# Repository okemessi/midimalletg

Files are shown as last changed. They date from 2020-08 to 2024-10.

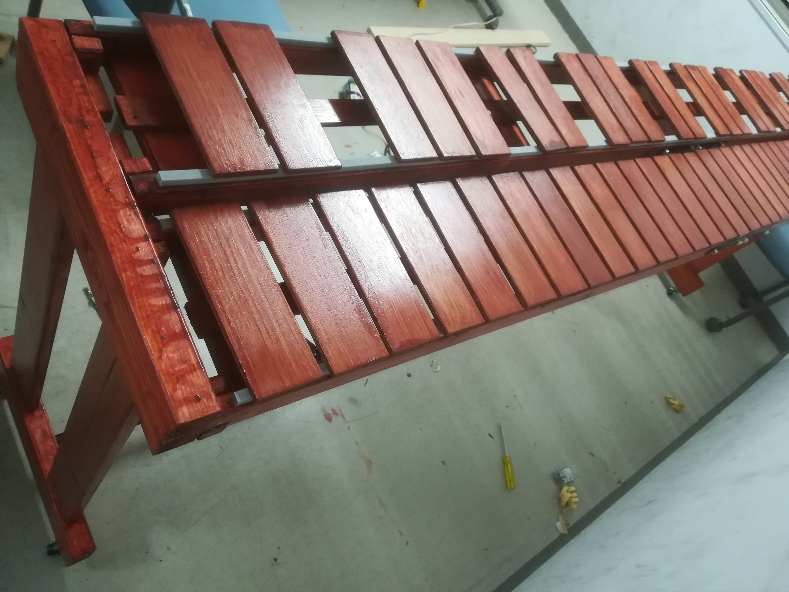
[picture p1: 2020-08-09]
docs/Hardware_example/Hardware(1).jpg

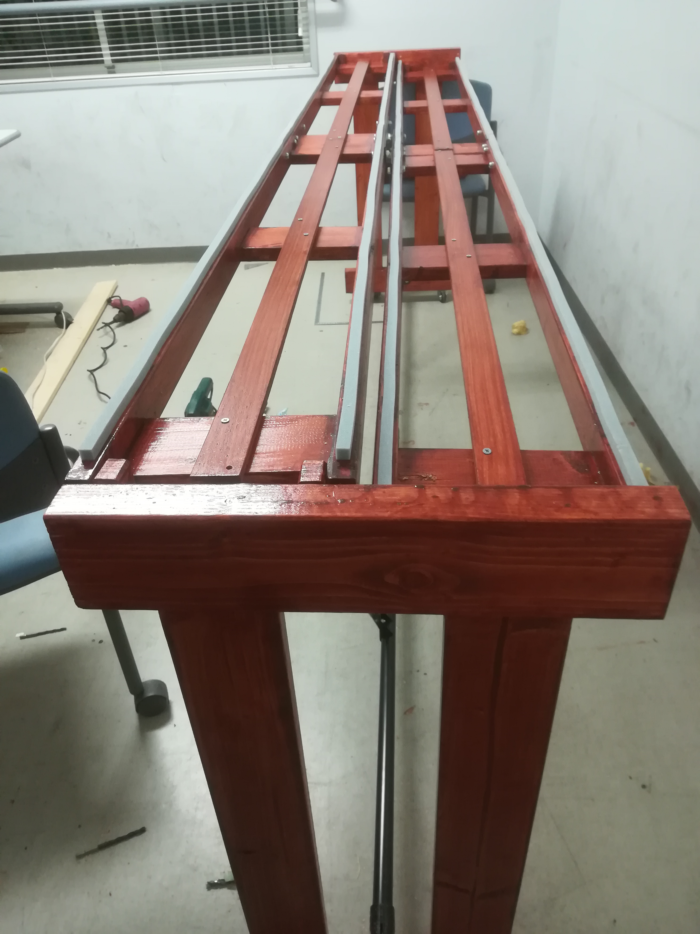
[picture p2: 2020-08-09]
docs/Hardware_example/Hardware(2).jpg

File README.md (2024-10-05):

Wiki: https://github.com/okemessi/midimalletg/wiki

# midimalletg

Midimalletg is a MIDI mallet controller for marimba/other keyboard percussion players. This project is developed as a hobby and personal project by okemessi. It is provided as-is because it is still under development. 

## Specifications

Detailed specifications will be added to the wiki page (https://github.com/okemessi/midimalletg/wiki) as they become available.

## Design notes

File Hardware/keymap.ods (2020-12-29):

id | ch |  |  | Key | +ofs | id | ch |  |  | Key | +ofs | id | ch
0 | 0 |  |  |  |  | 4 | 0 | SW | 1 | 0 | 16 | 8 | 0 | calib
 | 1 | NW | 1 | 1 | 17 |  | 1 |  | 2 | 2 | 18 |  | 1 | fader0
 | 2 |  | 2 | 3 | 19 |  | 2 |  | 3 | 4 | 20 |  | 2 | fader1
 | 3 |  | 3 | 6 | 22 |  | 3 |  | 4 | 5 | 21 |  | 3 | fader2
 | 4 |  | 4 | 8 | 24 |  | 4 |  | 5 | 7 | 23 |  | 4 | exp1
 | 5 |  | 5 | 10 | 26 |  | 5 |  | 6 | 9 | 25 |  | 5 | exp2
 | 6 |  | 6 | 13 | 29 |  | 6 |  | 7 | 11 | 27 |  | 6
 | 7 |  | 7 | 15 | 31 |  | 7 |  | 8 | 12 | 28 |  | 7
1 | 0 | NW | 8 | 18 | 34 | 5 | 0 | SW | 9 | 14 | 30 | 9 | 0 | button0
 | 1 |  | 9 | 20 | 36 |  | 1 |  | 10 | 16 | 32 |  | 1 | button1
 | 2 |  | 10 | 22 | 38 |  | 2 |  | 11 | 17 | 33 |  | 2 | button2
 | 3 |  | 11 | 25 | 41 |  | 3 |  | 12 | 19 | 35 |  | 3 | button3
 | 4 | SE | 1 | 28 | 44 | 5 | 4 |  | 13 | 21 | 37 |  | 4 | oct+
 | 5 |  | 2 | 29 | 45 |  | 5 |  | 14 | 23 | 39 |  | 5 | oct-
 | 6 |  | 3 | 31 | 47 |  | 6 |  | 15 | 24 | 40 |  | 6 | pedal1
 | 7 |  | 4 | 33 | 49 |  | 7 |  | 16 | 26 | 42 |  | 7 | pedal2
2 | 0 | SE | 5 | 35 | 51 | 6 | 0 | NE | 1 | 27 | 43
 | 1 |  | 6 | 36 | 52 |  | 1 |  | 2 | 30 | 46
 | 2 |  | 7 | 38 | 54 |  | 2 |  | 3 | 32 | 48
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

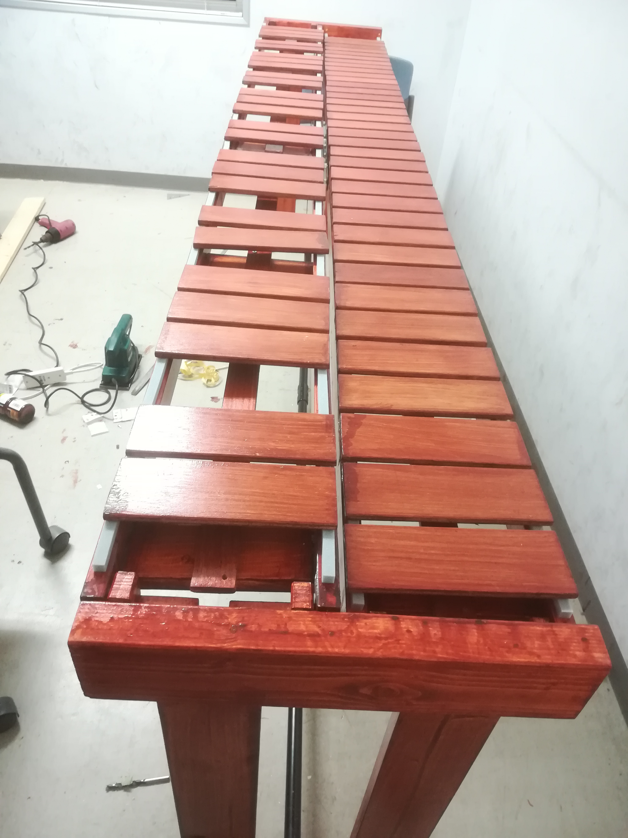
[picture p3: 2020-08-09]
docs/Hardware_example/Hardware.jpg

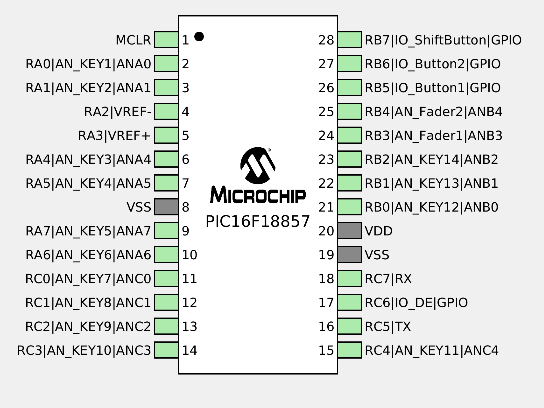
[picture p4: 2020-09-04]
docs/MCUs_pin_assign/chip4.png

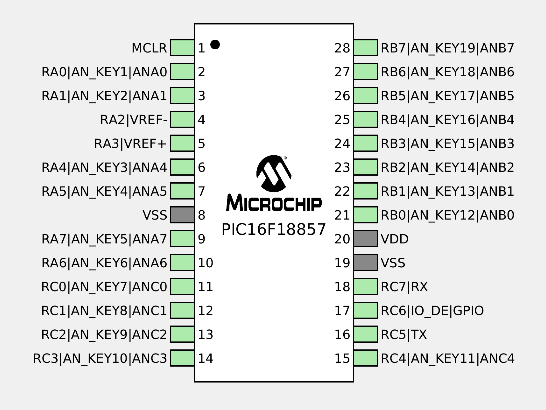
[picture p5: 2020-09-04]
docs/MCUs_pin_assign/chip3.png

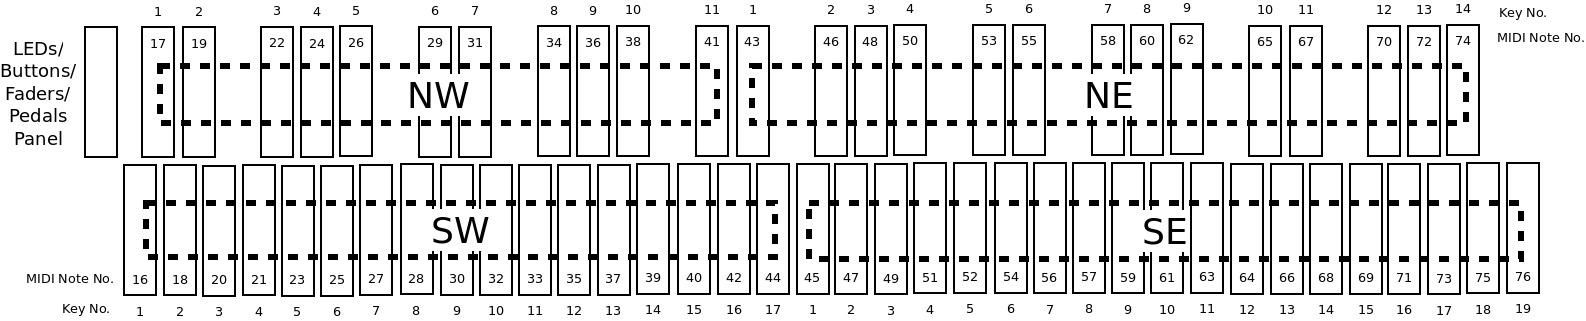
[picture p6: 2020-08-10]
docs/keymap/keymap.png

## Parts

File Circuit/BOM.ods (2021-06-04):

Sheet: Packed
Reference | Value | Reference | Value | quantity |  | Footprint | Datasheet | fader
R21 | 220 | R-25221 | 100 | 1 | 100 | 100 | ~ | Mother
U1 | 4051 | I-10914 | 40 | 11 | 440 | Package_DIP:DIP-16_W7.62mm | http://www.intersil.com/content/dam/Intersil/documents/cd40/cd4051bms-52bms-53bms.pdf | fader
C3 | 0.01u | P-11150 | 5 | 1 | 5 | Capacitor_THT:C_Disc_D3.0mm_W2.0mm_P2.50mm | ~ | Display
C2 | 0.1u | P-00090 | 100 | 4 | 400 | Capacitor_THT:C_Disc_D3.0mm_W1.6mm_P2.50mm | ~ | fader
R1 | 10k | R-25103 | 100 | 1 | 100 | Resistor_THT:R_Axial_DIN0204_L3.6mm_D1.6mm_P7.62mm_Horizontal | ~ | fader
C1 | 10u | P-06197 | 80 | 2 | 160 | Capacitor_THT:CP_Radial_D5.0mm_P2.50mm | ~ | fader
C22 | 10uF | P-05103 | 30 | 1 | 30 | Capacitor_THT:C_Disc_D5.0mm_W2.5mm_P5.00mm | ~ | Mother
R3 | 1k | R-25102 | 100 | 1 | 100 | Resistor_THT:R_Axial_DIN0204_L3.6mm_D1.6mm_P7.62mm_Horizontal | ~ | Mother
R1 | 1Meg | R-07866 | 100 | 1 | 100 | Resistor_THT:R_Axial_DIN0204_L3.6mm_D1.6mm_P7.62mm_Horizontal | ~ | terminal5
D3 | I-08332 | I-08332 | 10 | 1 | 10 | Diode_THT:D_DO-41_SOD81_P2.54mm_Vertical_AnodeUp | http://www.vishay.com/docs/88503/1n4001.pdf | Mother
D2 | 1SS178 | I-10516 | 10 | 1 | 10 | Diode_THT:D_DO-35_SOD27_P2.54mm_Vertical_AnodeUp | ~ | Mother
R10 | 4.7k | R-25472 | 100 | 1 | 100 | Resistor_THT:R_Axial_DIN0204_L3.6mm_D1.6mm_P7.62mm_Horizontal | ~ | Display
RV5 | 50kA | P-07210 | 40 | 1 | 40 |  | ~ | peripheral
RV4 | 50KB | P-09239 | 100 | 4 | 400 |  | ~ | peripheral
U1 | 74HC00 | I-14052 | 20 | 2 | 40 | Package_DIP:DIP-14_W7.62mm | http://www.ti.com/lit/gpn/sn74hc00 | Mother
J12 | AudioJack2 | C-14813 | 70 | 2 | 140 |  | ~ | peripheral
J10 | AudioJack3_SwitchTR | C-06765 | 90 | 2 | 180 |  | ~ | peripheral
U2 | BP5293-33 | M-15148 | 250 | 1 | 250 | Package_TO_SOT_THT:TO-220-3_Vertical | https://akizukidenshi.com/download/ds/rohm/BP5293_DataSheet_J_VerC_161013.pdf | Mother
U3 | BP5293-50 | M-15209 | 250 | 1 | 250 | Package_TO_SOT_THT:TO-220-3_Vertical | https://akizukidenshi.com/download/ds/rohm/BP5293_DataSheet_J_VerC_161013.pdf | Mother
J7 | Conn_01x02_Female | C-05779 | 80 | 3 | 240 |  | ~ | peripheral
J3 | Conn_01x02_Male | C-01627 | 50 | 3 | 150 | Connector_PinHeader_2.54mm:PinHeader_1x02_P2.54mm_Horizontal | ~ | fader
J9 | Conn_02x08_Female | C-05780 | 100 | 3 | 300 |  | ~ | peripheral
J2 | Conn_02x08_Male | C-00148 | 100 | 3 | 300 | Connector_PinHeader_2.54mm:PinHeader_2x08_P2.54mm_Horizontal | ~ | terminal5
J44 | DB15_Female | C-00026 | 50 | 1 | 50 |  | ~ | peripheral
J41 | DB15_Male | C-00025 | 50 | 1 | 50 |  | ~ | peripheral
 | DB15_Shell | C-00032 | 100 | 2 | 200
J26 | DIN-5_180degree | C-10456 | 60 | 2 | 120 |  | http://www.mouser.com/ds/2/18/40_c091_abd_e-75918.pdf | peripheral
BAR1 | HDSP-4830_2 | I-05347 | 120 | 1 | 120 | Display:HDSP-4830 | https://docs.broadcom.com/docs/AV02-1798EN | Display
J28 | Jack-DC | C-06299 | 40 | 1 | 40 |  | ~ | peripheral
D1 | LED | I-11655 | 20 | 1 | 20 | LED_THT:LED_D3.0mm,2.1v | ~ | Mother
D4 | LED | I-11657 | 20 | 4 | 80 | LED_THT:LED_D3.0mm | ~ | Display
AFF4 | LTS-6960HR | I-00639 | 40 | 3 | 120 | Display_7Segment:7SegmentLED_LTS6760_LTS6780 | https://datasheet.octopart.com/LTS-6960HR-Lite-On-datasheet-11803242.pdf | Display
AFF5 | LTS-6960HR | I-12923 | 50 | 2 | 100 | Display_7Segment:7SegmentLED_LTS6760_LTS6780 | https://datasheet.octopart.com/LTS-6960HR-Lite-On-datasheet-11803242.pdf | Display
U2 | PIC16F18854-SO | I-11888 | 170 | 1 | 170 | Package_DIP:DIP-28_W7.62mm | http://ww1.microchip.com/downloads/en/DeviceDoc/PIC16(L)F18854%20Data%20Sheet_DS40001826C.pdf | Display
U4 | PIC32MX110F016B-I_SP | I-05849 | 180 | 1 | 180 | Package_DIP:DIP-28_W7.62mm | http://ww1.microchip.com/downloads/en/DeviceDoc/61168E.pdf | Manufacturer URL | http://www.microchip.com | Package Specification | http://www.microchip.com/stellent/groups/techpub_sg/documents/packagingspec/en012702.pdf | Product URL | http://www.microchip.com/PIC32MX110F016B | Rev. E | Through Hole | 28-Lead Plastic Dual In-Line, 34.86 x 6.79 mm Body, 2.54 mm Pitch | C04-070B | IC | 1156563 | yes | fa7413a09ebb98f6 | Microchip | SPDIP-SP28 | 1359970709 | E7E3DC04-7D64-40B1-9461-E4D614E67543 | Mother
MK1 | Piezo | P-09799 | 70 | 61 | 4270 |  | ~ | peripheral
F1 | RXEF050 | P-01355 | 30 | 1 | 30 | Capacitor_THT:C_Disc_D8.0mm_W2.5mm_P5.00mm | https://akizukidenshi.com/download/ds/tyco/rxef050.pdf | Mother
SW1 | SW_Panel | P-15666 | 65 | 4 | 260 |  | ~ | peripheral
SW2 | SW_Panel | P-15665 | 65 | 2 | 130 |  | ~ | peripheral
SW3 | SW_Panel | P-15667 | 65 | 2 | 130 |  | ~ | peripheral
U1 | TBD62783A | I-10957 | 60 | 1 | 60 | Package_DIP:DIP-18_W7.62mm | http://toshiba.semicon-storage.com/info/docget.jsp?did=30523&prodName=TBD62783APG | Display
U6 | TLP785 | I-07554 | 20 | 1 | 20 | Package_DIP:DIP-4_W7.62mm | https://toshiba.semicon-storage.com/info/docget.jsp?did=10569&prodName=TLP785 | Mother
U3 | ULN2803A | I-15065 | 50 | 1 | 50 | Package_DIP:DIP-18_W7.62mm | http://www.ti.com/lit/ds/symlink/uln2803a.pdf | Display
Board | Ctype | P-00517 | 60 | 10 | 600
 | Atype | P-07618 | 300 | 2 | 600
knob | fader | P-09246 | 30 | 4 | 120
 | vol | P-00253 | 20 | 1 | 20
snap | MPLAB | M-13854 | 2800 | 1 | 2800
 | vinyl wire | P-11091 | 600 | 2 | 1200
 | vinyl wire | P-11090 | 600 | 2 | 1200
 | Tin-plated wire | P-02220 | 230 | 1 | 230
sw | toggle | P-03774 | 80 | 1 | 80
 |  | P-14523 | 320 | 1 | 320
 | AudioJack2 | C-14813 | 70 | 2 | 140
 |  | P-15128 | 115 | 1 | 115

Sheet: BOM
Reference | Value | Footprint | Datasheet | fader
R21 | 220 | Resistor_THT:R_Axial_DIN0204_L3.6mm_D1.6mm_P7.62mm_Horizontal | ~ | Mother
R20 | 220 | Resistor_THT:R_Axial_DIN0204_L3.6mm_D1.6mm_P7.62mm_Horizontal | ~ | Mother
R22 | 220 | Resistor_THT:R_Axial_DIN0204_L3.6mm_D1.6mm_P7.62mm_Horizontal | ~ | Mother
R23 | 220 | Resistor_THT:R_Axial_DIN0204_L3.6mm_D1.6mm_P7.62mm_Horizontal | ~ | Mother
R1 | 220 | Resistor_THT:R_Axial_DIN0204_L3.6mm_D1.6mm_P7.62mm_Horizontal | ~ | Display
R7 | 220 | Resistor_THT:R_Axial_DIN0204_L3.6mm_D1.6mm_P7.62mm_Horizontal | ~ | Display
R6 | 220 | Resistor_THT:R_Axial_DIN0204_L3.6mm_D1.6mm_P7.62mm_Horizontal | ~ | Display
R5 | 220 | Resistor_THT:R_Axial_DIN0204_L3.6mm_D1.6mm_P7.62mm_Horizontal | ~ | Display
R4 | 220 | Resistor_THT:R_Axial_DIN0204_L3.6mm_D1.6mm_P7.62mm_Horizontal | ~ | Display
R3 | 220 | Resistor_THT:R_Axial_DIN0204_L3.6mm_D1.6mm_P7.62mm_Horizontal | ~ | Display
R2 | 220 | Resistor_THT:R_Axial_DIN0204_L3.6mm_D1.6mm_P7.62mm_Horizontal | ~ | Display
R9 | 220 | Resistor_THT:R_Axial_DIN0204_L3.6mm_D1.6mm_P7.62mm_Horizontal | ~ | terminal5
R10 | 220 | Resistor_THT:R_Axial_DIN0204_L3.6mm_D1.6mm_P7.62mm_Horizontal | ~ | terminal5
R11 | 220 | Resistor_THT:R_Axial_DIN0204_L3.6mm_D1.6mm_P7.62mm_Horizontal | ~ | terminal5
R12 | 220 | Resistor_THT:R_Axial_DIN0204_L3.6mm_D1.6mm_P7.62mm_Horizontal | ~ | terminal5
R13 | 220 | Resistor_THT:R_Axial_DIN0204_L3.6mm_D1.6mm_P7.62mm_Horizontal | ~ | terminal5
R14 | 220 | Resistor_THT:R_Axial_DIN0204_L3.6mm_D1.6mm_P7.62mm_Horizontal | ~ | terminal5
R15 | 220 | Resistor_THT:R_Axial_DIN0204_L3.6mm_D1.6mm_P7.62mm_Horizontal | ~ | terminal5
R16 | 220 | Resistor_THT:R_Axial_DIN0204_L3.6mm_D1.6mm_P7.62mm_Horizontal | ~ | terminal5
R9 | 220 | Resistor_THT:R_Axial_DIN0204_L3.6mm_D1.6mm_P7.62mm_Horizontal | ~ | terminal7
R10 | 220 | Resistor_THT:R_Axial_DIN0204_L3.6mm_D1.6mm_P7.62mm_Horizontal | ~ | terminal7
R11 | 220 | Resistor_THT:R_Axial_DIN0204_L3.6mm_D1.6mm_P7.62mm_Horizontal | ~ | terminal7
R12 | 220 | Resistor_THT:R_Axial_DIN0204_L3.6mm_D1.6mm_P7.62mm_Horizontal | ~ | terminal7
R13 | 220 | Resistor_THT:R_Axial_DIN0204_L3.6mm_D1.6mm_P7.62mm_Horizontal | ~ | terminal7
R14 | 220 | Resistor_THT:R_Axial_DIN0204_L3.6mm_D1.6mm_P7.62mm_Horizontal | ~ | terminal7
R15 | 220 | Resistor_THT:R_Axial_DIN0204_L3.6mm_D1.6mm_P7.62mm_Horizontal | ~ | terminal7
R16 | 220 | Resistor_THT:R_Axial_DIN0204_L3.6mm_D1.6mm_P7.62mm_Horizontal | ~ | terminal7
R9 | 220 | Resistor_THT:R_Axial_DIN0204_L3.6mm_D1.6mm_P7.62mm_Horizontal | ~ | terminal4N
R10 | 220 | Resistor_THT:R_Axial_DIN0204_L3.6mm_D1.6mm_P7.62mm_Horizontal | ~ | terminal4N
R11 | 220 | Resistor_THT:R_Axial_DIN0204_L3.6mm_D1.6mm_P7.62mm_Horizontal | ~ | terminal4N
R12 | 220 | Resistor_THT:R_Axial_DIN0204_L3.6mm_D1.6mm_P7.62mm_Horizontal | ~ | terminal4N
R13 | 220 | Resistor_THT:R_Axial_DIN0204_L3.6mm_D1.6mm_P7.62mm_Horizontal | ~ | terminal4N
R14 | 220 | Resistor_THT:R_Axial_DIN0204_L3.6mm_D1.6mm_P7.62mm_Horizontal | ~ | terminal4N
R15 | 220 | Resistor_THT:R_Axial_DIN0204_L3.6mm_D1.6mm_P7.62mm_Horizontal | ~ | terminal4N
R16 | 220 | Resistor_THT:R_Axial_DIN0204_L3.6mm_D1.6mm_P7.62mm_Horizontal | ~ | terminal4N
R9 | 220 | Resistor_THT:R_Axial_DIN0204_L3.6mm_D1.6mm_P7.62mm_Horizontal | ~ | terminal4S
R10 | 220 | Resistor_THT:R_Axial_DIN0204_L3.6mm_D1.6mm_P7.62mm_Horizontal | ~ | terminal4S
R11 | 220 | Resistor_THT:R_Axial_DIN0204_L3.6mm_D1.6mm_P7.62mm_Horizontal | ~ | terminal4S
R12 | 220 | Resistor_THT:R_Axial_DIN0204_L3.6mm_D1.6mm_P7.62mm_Horizontal | ~ | terminal4S
R13 | 220 | Resistor_THT:R_Axial_DIN0204_L3.6mm_D1.6mm_P7.62mm_Horizontal | ~ | terminal4S
R14 | 220 | Resistor_THT:R_Axial_DIN0204_L3.6mm_D1.6mm_P7.62mm_Horizontal | ~ | terminal4S
R15 | 220 | Resistor_THT:R_Axial_DIN0204_L3.6mm_D1.6mm_P7.62mm_Horizontal | ~ | terminal4S
R16 | 220 | Resistor_THT:R_Axial_DIN0204_L3.6mm_D1.6mm_P7.62mm_Horizontal | ~ | terminal4S
R9 | 220 | Resistor_THT:R_Axial_DIN0204_L3.6mm_D1.6mm_P7.62mm_Horizontal | ~ | terminal1-2-3-6
R10 | 220 | Resistor_THT:R_Axial_DIN0204_L3.6mm_D1.6mm_P7.62mm_Horizontal | ~ | terminal1-2-3-6
R11 | 220 | Resistor_THT:R_Axial_DIN0204_L3.6mm_D1.6mm_P7.62mm_Horizontal | ~ | terminal1-2-3-6
R12 | 220 | Resistor_THT:R_Axial_DIN0204_L3.6mm_D1.6mm_P7.62mm_Horizontal | ~ | terminal1-2-3-6
R13 | 220 | Resistor_THT:R_Axial_DIN0204_L3.6mm_D1.6mm_P7.62mm_Horizontal | ~ | terminal1-2-3-6
R14 | 220 | Resistor_THT:R_Axial_DIN0204_L3.6mm_D1.6mm_P7.62mm_Horizontal | ~ | terminal1-2-3-6
R15 | 220 | Resistor_THT:R_Axial_DIN0204_L3.6mm_D1.6mm_P7.62mm_Horizontal | ~ | terminal1-2-3-6
R16 | 220 | Resistor_THT:R_Axial_DIN0204_L3.6mm_D1.6mm_P7.62mm_Horizontal | ~ | terminal1-2-3-6
R9 | 220 | Resistor_THT:R_Axial_DIN0204_L3.6mm_D1.6mm_P7.62mm_Horizontal | ~ | terminal1-2-3-6
R10 | 220 | Resistor_THT:R_Axial_DIN0204_L3.6mm_D1.6mm_P7.62mm_Horizontal | ~ | terminal1-2-3-6
R11 | 220 | Resistor_THT:R_Axial_DIN0204_L3.6mm_D1.6mm_P7.62mm_Horizontal | ~ | terminal1-2-3-6
R12 | 220 | Resistor_THT:R_Axial_DIN0204_L3.6mm_D1.6mm_P7.62mm_Horizontal | ~ | terminal1-2-3-6
R13 | 220 | Resistor_THT:R_Axial_DIN0204_L3.6mm_D1.6mm_P7.62mm_Horizontal | ~ | terminal1-2-3-6
R14 | 220 | Resistor_THT:R_Axial_DIN0204_L3.6mm_D1.6mm_P7.62mm_Horizontal | ~ | terminal1-2-3-6
R15 | 220 | Resistor_THT:R_Axial_DIN0204_L3.6mm_D1.6mm_P7.62mm_Horizontal | ~ | terminal1-2-3-6
R16 | 220 | Resistor_THT:R_Axial_DIN0204_L3.6mm_D1.6mm_P7.62mm_Horizontal | ~ | terminal1-2-3-6
R9 | 220 | Resistor_THT:R_Axial_DIN0204_L3.6mm_D1.6mm_P7.62mm_Horizontal | ~ | terminal1-2-3-6
R10 | 220 | Resistor_THT:R_Axial_DIN0204_L3.6mm_D1.6mm_P7.62mm_Horizontal | ~ | terminal1-2-3-6
R11 | 220 | Resistor_THT:R_Axial_DIN0204_L3.6mm_D1.6mm_P7.62mm_Horizontal | ~ | terminal1-2-3-6
R12 | 220 | Resistor_THT:R_Axial_DIN0204_L3.6mm_D1.6mm_P7.62mm_Horizontal | ~ | terminal1-2-3-6
R13 | 220 | Resistor_THT:R_Axial_DIN0204_L3.6mm_D1.6mm_P7.62mm_Horizontal | ~ | terminal1-2-3-6
R14 | 220 | Resistor_THT:R_Axial_DIN0204_L3.6mm_D1.6mm_P7.62mm_Horizontal | ~ | terminal1-2-3-6
R15 | 220 | Resistor_THT:R_Axial_DIN0204_L3.6mm_D1.6mm_P7.62mm_Horizontal | ~ | terminal1-2-3-6
R16 | 220 | Resistor_THT:R_Axial_DIN0204_L3.6mm_D1.6mm_P7.62mm_Horizontal | ~ | terminal1-2-3-6
R9 | 220 | Resistor_THT:R_Axial_DIN0204_L3.6mm_D1.6mm_P7.62mm_Horizontal | ~ | terminal1-2-3-6
R10 | 220 | Resistor_THT:R_Axial_DIN0204_L3.6mm_D1.6mm_P7.62mm_Horizontal | ~ | terminal1-2-3-6
R11 | 220 | Resistor_THT:R_Axial_DIN0204_L3.6mm_D1.6mm_P7.62mm_Horizontal | ~ | terminal1-2-3-6
R12 | 220 | Resistor_THT:R_Axial_DIN0204_L3.6mm_D1.6mm_P7.62mm_Horizontal | ~ | terminal1-2-3-6
R13 | 220 | Resistor_THT:R_Axial_DIN0204_L3.6mm_D1.6mm_P7.62mm_Horizontal | ~ | terminal1-2-3-6
R14 | 220 | Resistor_THT:R_Axial_DIN0204_L3.6mm_D1.6mm_P7.62mm_Horizontal | ~ | terminal1-2-3-6
R15 | 220 | Resistor_THT:R_Axial_DIN0204_L3.6mm_D1.6mm_P7.62mm_Horizontal | ~ | terminal1-2-3-6
R16 | 220 | Resistor_THT:R_Axial_DIN0204_L3.6mm_D1.6mm_P7.62mm_Horizontal | ~ | terminal1-2-3-6
R9 | 220 | Resistor_THT:R_Axial_DIN0204_L3.6mm_D1.6mm_P7.62mm_Horizontal | ~ | terminal1-2-3-6
R10 | 220 | Resistor_THT:R_Axial_DIN0204_L3.6mm_D1.6mm_P7.62mm_Horizontal | ~ | terminal1-2-3-6
R11 | 220 | Resistor_THT:R_Axial_DIN0204_L3.6mm_D1.6mm_P7.62mm_Horizontal | ~ | terminal1-2-3-6
R12 | 220 | Resistor_THT:R_Axial_DIN0204_L3.6mm_D1.6mm_P7.62mm_Horizontal | ~ | terminal1-2-3-6
R13 | 220 | Resistor_THT:R_Axial_DIN0204_L3.6mm_D1.6mm_P7.62mm_Horizontal | ~ | terminal1-2-3-6
R14 | 220 | Resistor_THT:R_Axial_DIN0204_L3.6mm_D1.6mm_P7.62mm_Horizontal | ~ | terminal1-2-3-6
R15 | 220 | Resistor_THT:R_Axial_DIN0204_L3.6mm_D1.6mm_P7.62mm_Horizontal | ~ | terminal1-2-3-6
R16 | 220 | Resistor_THT:R_Axial_DIN0204_L3.6mm_D1.6mm_P7.62mm_Horizontal | ~ | terminal1-2-3-6
U1 | 4051 | Package_DIP:DIP-16_W7.62mm | http://www.intersil.com/content/dam/Intersil/documents/cd40/cd4051bms-52bms-53bms.pdf | fader
U5 | 4051 | Package_DIP:DIP-16_W7.62mm | http://www.intersil.com/content/dam/Intersil/documents/cd40/cd4051bms-52bms-53bms.pdf | Mother
U1 | 4051 | Package_DIP:DIP-16_W7.62mm | http://www.intersil.com/content/dam/Intersil/documents/cd40/cd4051bms-52bms-53bms.pdf | terminal5
U1 | 4051 | Package_DIP:DIP-16_W7.62mm | http://www.intersil.com/content/dam/Intersil/documents/cd40/cd4051bms-52bms-53bms.pdf | terminal7
U1 | 4051 | Package_DIP:DIP-16_W7.62mm | http://www.intersil.com/content/dam/Intersil/documents/cd40/cd4051bms-52bms-53bms.pdf | terminal4N
U1 | 4051 | Package_DIP:DIP-16_W7.62mm | http://www.intersil.com/content/dam/Intersil/documents/cd40/cd4051bms-52bms-53bms.pdf | terminal4S
U1 | 4051 | Package_DIP:DIP-16_W7.62mm | http://www.intersil.com/content/dam/Intersil/documents/cd40/cd4051bms-52bms-53bms.pdf | terminal1-2-3-6
U1 | 4051 | Package_DIP:DIP-16_W7.62mm | http://www.intersil.com/content/dam/Intersil/documents/cd40/cd4051bms-52bms-53bms.pdf | terminal1-2-3-6
U1 | 4051 | Package_DIP:DIP-16_W7.62mm | http://www.intersil.com/content/dam/Intersil/documents/cd40/cd4051bms-52bms-53bms.pdf | terminal1-2-3-6
U1 | 4051 | Package_DIP:DIP-16_W7.62mm | http://www.intersil.com/content/dam/Intersil/documents/cd40/cd4051bms-52bms-53bms.pdf | terminal1-2-3-6
U1 | 4051 | Package_DIP:DIP-16_W7.62mm | http://www.intersil.com/content/dam/Intersil/documents/cd40/cd4051bms-52bms-53bms.pdf | terminal1-2-3-6
C3 | 0.01u | Capacitor_THT:C_Disc_D3.0mm_W2.0mm_P2.50mm | ~ | Display
C2 | 0.1u | Capacitor_THT:C_Disc_D3.0mm_W1.6mm_P2.50mm | ~ | fader
C3 | 0.1u | Capacitor_THT:C_Disc_D3.0mm_W1.6mm_P2.50mm | ~ | fader
C4 | 0.1u | Capacitor_THT:C_Disc_D3.0mm_W1.6mm_P2.50mm | ~ | fader
C5 | 0.1u | Capacitor_THT:C_Disc_D3.0mm_W1.6mm_P2.50mm | ~ | fader
C6 | 0.1u | Capacitor_THT:C_Disc_D3.0mm_W1.6mm_P2.50mm | ~ | fader
C7 | 0.1u | Capacitor_THT:C_Disc_D3.0mm_W1.6mm_P2.50mm | ~ | fader
C8 | 0.1u | Capacitor_THT:C_Disc_D3.0mm_W1.6mm_P2.50mm | ~ | fader
C9 | 0.1u | Capacitor_THT:C_Disc_D3.0mm_W1.6mm_P2.50mm | ~ | fader
C10 | 0.1u | Capacitor_THT:C_Disc_D3.0mm_W1.6mm_P2.50mm | ~ | fader
C10 | 0.1u | Capacitor_THT:C_Disc_D3.0mm_W1.6mm_P2.50mm | ~ | Mother
C11 | 0.1u | Capacitor_THT:C_Disc_D3.0mm_W1.6mm_P2.50mm | ~ | Mother
C6 | 0.1u | Capacitor_THT:C_Disc_D3.0mm_W1.6mm_P2.50mm | ~ | Mother
C20 | 0.1u | Capacitor_THT:C_Disc_D3.0mm_W1.6mm_P2.50mm | ~ | Mother
C19 | 0.1u | Capacitor_THT:C_Disc_D3.0mm_W1.6mm_P2.50mm | ~ | Mother
C18 | 0.1u | Capacitor_THT:C_Disc_D3.0mm_W1.6mm_P2.50mm | ~ | Mother
C17 | 0.1u | Capacitor_THT:C_Disc_D3.0mm_W1.6mm_P2.50mm | ~ | Mother
C16 | 0.1u | Capacitor_THT:C_Disc_D3.0mm_W1.6mm_P2.50mm | ~ | Mother
C15 | 0.1u | Capacitor_THT:C_Disc_D3.0mm_W1.6mm_P2.50mm | ~ | Mother
C14 | 0.1u | Capacitor_THT:C_Disc_D3.0mm_W1.6mm_P2.50mm | ~ | Mother
C12 | 0.1u | Capacitor_THT:C_Disc_D3.0mm_W1.6mm_P2.50mm | ~ | Mother
C1 | 0.1u | Capacitor_THT:C_Disc_D3.0mm_W1.6mm_P2.50mm | ~ | Mother
C5 | 0.1u | Capacitor_THT:C_Disc_D3.0mm_W1.6mm_P2.50mm | ~ | Mother
C8 | 0.1u | Capacitor_THT:C_Disc_D3.0mm_W1.6mm_P2.50mm | ~ | Mother
C2 | 0.1u | Capacitor_THT:C_Disc_D3.0mm_W1.6mm_P2.50mm | ~ | Display
C1 | 0.1u | Capacitor_THT:C_Disc_D3.0mm_W1.6mm_P2.50mm | ~ | Display
C2 | 0.1u | Capacitor_THT:C_Disc_D3.0mm_W1.6mm_P2.50mm | ~ | terminal5
C2 | 0.1u | Capacitor_THT:C_Disc_D3.0mm_W1.6mm_P2.50mm | ~ | terminal7
C2 | 0.1u | Capacitor_THT:C_Disc_D3.0mm_W1.6mm_P2.50mm | ~ | terminal4N
C3 | 0.1u | Capacitor_THT:C_Disc_D3.0mm_W1.6mm_P2.50mm | ~ | terminal4N
C2 | 0.1u | Capacitor_THT:C_Disc_D3.0mm_W1.6mm_P2.50mm | ~ | terminal4S
C2 | 0.1u | Capacitor_THT:C_Disc_D3.0mm_W1.6mm_P2.50mm | ~ | terminal1-2-3-6
C2 | 0.1u | Capacitor_THT:C_Disc_D3.0mm_W1.6mm_P2.50mm | ~ | terminal1-2-3-6
C2 | 0.1u | Capacitor_THT:C_Disc_D3.0mm_W1.6mm_P2.50mm | ~ | terminal1-2-3-6
C2 | 0.1u | Capacitor_THT:C_Disc_D3.0mm_W1.6mm_P2.50mm | ~ | terminal1-2-3-6
C2 | 0.1u | Capacitor_THT:C_Disc_D3.0mm_W1.6mm_P2.50mm | ~ | terminal1-2-3-6
R1 | 10k | Resistor_THT:R_Axial_DIN0204_L3.6mm_D1.6mm_P7.62mm_Horizontal | ~ | fader
R2 | 10k | Resistor_THT:R_Axial_DIN0204_L3.6mm_D1.6mm_P7.62mm_Horizontal | ~ | fader
R3 | 10k | Resistor_THT:R_Axial_DIN0204_L3.6mm_D1.6mm_P7.62mm_Horizontal | ~ | fader
R4 | 10k | Resistor_THT:R_Axial_DIN0204_L3.6mm_D1.6mm_P7.62mm_Horizontal | ~ | fader
R5 | 10k | Resistor_THT:R_Axial_DIN0204_L3.6mm_D1.6mm_P7.62mm_Horizontal | ~ | fader
R6 | 10k | Resistor_THT:R_Axial_DIN0204_L3.6mm_D1.6mm_P7.62mm_Horizontal | ~ | fader
R7 | 10k | Resistor_THT:R_Axial_DIN0204_L3.6mm_D1.6mm_P7.62mm_Horizontal | ~ | fader
R8 | 10k | Resistor_THT:R_Axial_DIN0204_L3.6mm_D1.6mm_P7.62mm_Horizontal | ~ | fader
R9 | 10k | Resistor_THT:R_Axial_DIN0204_L3.6mm_D1.6mm_P7.62mm_Horizontal | ~ | fader
R10 | 10k | Resistor_THT:R_Axial_DIN0204_L3.6mm_D1.6mm_P7.62mm_Horizontal | ~ | fader
R2 | 10k | Resistor_THT:R_Axial_DIN0204_L3.6mm_D1.6mm_P7.62mm_Horizontal | ~ | Mother
R12 | 10k | Resistor_THT:R_Axial_DIN0204_L3.6mm_D1.6mm_P7.62mm_Horizontal | ~ | Mother
R13 | 10k | Resistor_THT:R_Axial_DIN0204_L3.6mm_D1.6mm_P7.62mm_Horizontal | ~ | Mother
R14 | 10k | Resistor_THT:R_Axial_DIN0204_L3.6mm_D1.6mm_P7.62mm_Horizontal | ~ | Mother
R15 | 10k | Resistor_THT:R_Axial_DIN0204_L3.6mm_D1.6mm_P7.62mm_Horizontal | ~ | Mother
R16 | 10k | Resistor_THT:R_Axial_DIN0204_L3.6mm_D1.6mm_P7.62mm_Horizontal | ~ | Mother
R17 | 10k | Resistor_THT:R_Axial_DIN0204_L3.6mm_D1.6mm_P7.62mm_Horizontal | ~ | Mother
R18 | 10k | Resistor_THT:R_Axial_DIN0204_L3.6mm_D1.6mm_P7.62mm_Horizontal | ~ | Mother
R19 | 10k | Resistor_THT:R_Axial_DIN0204_L3.6mm_D1.6mm_P7.62mm_Horizontal | ~ | Mother
R4 | 10k | Resistor_THT:R_Axial_DIN0204_L3.6mm_D1.6mm_P7.62mm_Horizontal | ~ | Mother
R5 | 10k | Resistor_THT:R_Axial_DIN0204_L3.6mm_D1.6mm_P7.62mm_Horizontal | ~ | Mother
R6 | 10k | Resistor_THT:R_Axial_DIN0204_L3.6mm_D1.6mm_P7.62mm_Horizontal | ~ | Mother
R7 | 10k | Resistor_THT:R_Axial_DIN0204_L3.6mm_D1.6mm_P7.62mm_Horizontal | ~ | Mother
R8 | 10k | Resistor_THT:R_Axial_DIN0204_L3.6mm_D1.6mm_P7.62mm_Horizontal | ~ | Mother
R9 | 10k | Resistor_THT:R_Axial_DIN0204_L3.6mm_D1.6mm_P7.62mm_Horizontal | ~ | Mother
R10 | 10k | Resistor_THT:R_Axial_DIN0204_L3.6mm_D1.6mm_P7.62mm_Horizontal | ~ | Mother
R11 | 10k | Resistor_THT:R_Axial_DIN0204_L3.6mm_D1.6mm_P7.62mm_Horizontal | ~ | Mother
R8 | 10k | Resistor_THT:R_Axial_DIN0204_L3.6mm_D1.6mm_P7.62mm_Horizontal | ~ | Display
C1 | 10u | Capacitor_THT:CP_Radial_D5.0mm_P2.50mm | ~ | fader
C7 | 10u | Capacitor_THT:CP_Radial_D5.0mm_P2.50mm | ~ | Mother
C2 | 10u | Capacitor_THT:CP_Radial_D5.0mm_P2.50mm | ~ | Mother
C3 | 10u | Capacitor_THT:CP_Radial_D5.0mm_P2.50mm | ~ | Mother
C9 | 10u | Capacitor_THT:CP_Radial_D5.0mm_P2.50mm | ~ | Mother
C4 | 10u | Capacitor_THT:CP_Radial_D5.0mm_P2.50mm | ~ | Mother
C21 | 10u | Capacitor_THT:C_Axial_L5.1mm_D3.1mm_P7.50mm_Horizontal | ~ | Mother
C4 | 10u | Capacitor_THT:CP_Radial_D5.0mm_P2.50mm | ~ | Display
C1 | 10u | Capacitor_THT:CP_Radial_D5.0mm_P2.50mm | ~ | terminal5
C1 | 10u | Capacitor_THT:CP_Radial_D5.0mm_P2.50mm | ~ | terminal7
C1 | 10u | Capacitor_THT:CP_Radial_D5.0mm_P2.50mm | ~ | terminal4N
C1 | 10u | Capacitor_THT:CP_Radial_D5.0mm_P2.50mm | ~ | terminal4S
C1 | 10u | Capacitor_THT:CP_Radial_D5.0mm_P2.50mm | ~ | terminal1-2-3-6
C1 | 10u | Capacitor_THT:CP_Radial_D5.0mm_P2.50mm | ~ | terminal1-2-3-6
C1 | 10u | Capacitor_THT:CP_Radial_D5.0mm_P2.50mm | ~ | terminal1-2-3-6
C1 | 10u | Capacitor_THT:CP_Radial_D5.0mm_P2.50mm | ~ | terminal1-2-3-6
C1 | 10u | Capacitor_THT:CP_Radial_D5.0mm_P2.50mm | ~ | terminal1-2-3-6
C22 | 10uF | Capacitor_THT:C_Disc_D5.0mm_W2.5mm_P5.00mm | ~ | Mother
R3 | 1k | Resistor_THT:R_Axial_DIN0204_L3.6mm_D1.6mm_P7.62mm_Horizontal | ~ | Mother
R1 | 1k | Resistor_THT:R_Axial_DIN0204_L3.6mm_D1.6mm_P7.62mm_Horizontal | ~ | Mother
R1 | 1Meg | Resistor_THT:R_Axial_DIN0204_L3.6mm_D1.6mm_P7.62mm_Horizontal | ~ | terminal5
R2 | 1Meg | Resistor_THT:R_Axial_DIN0204_L3.6mm_D1.6mm_P7.62mm_Horizontal | ~ | terminal5
R3 | 1Meg | Resistor_THT:R_Axial_DIN0204_L3.6mm_D1.6mm_P7.62mm_Horizontal | ~ | terminal5
R4 | 1Meg | Resistor_THT:R_Axial_DIN0204_L3.6mm_D1.6mm_P7.62mm_Horizontal | ~ | terminal5
R5 | 1Meg | Resistor_THT:R_Axial_DIN0204_L3.6mm_D1.6mm_P7.62mm_Horizontal | ~ | terminal5
R6 | 1Meg | Resistor_THT:R_Axial_DIN0204_L3.6mm_D1.6mm_P7.62mm_Horizontal | ~ | terminal5
R7 | 1Meg | Resistor_THT:R_Axial_DIN0204_L3.6mm_D1.6mm_P7.62mm_Horizontal | ~ | terminal5
R1 | 1Meg | Resistor_THT:R_Axial_DIN0204_L3.6mm_D1.6mm_P7.62mm_Horizontal | ~ | terminal7
R2 | 1Meg | Resistor_THT:R_Axial_DIN0204_L3.6mm_D1.6mm_P7.62mm_Horizontal | ~ | terminal7
R3 | 1Meg | Resistor_THT:R_Axial_DIN0204_L3.6mm_D1.6mm_P7.62mm_Horizontal | ~ | terminal7
R4 | 1Meg | Resistor_THT:R_Axial_DIN0204_L3.6mm_D1.6mm_P7.62mm_Horizontal | ~ | terminal7
R5 | 1Meg | Resistor_THT:R_Axial_DIN0204_L3.6mm_D1.6mm_P7.62mm_Horizontal | ~ | terminal7
R6 | 1Meg | Resistor_THT:R_Axial_DIN0204_L3.6mm_D1.6mm_P7.62mm_Horizontal | ~ | terminal7
R5 | 1Meg | Resistor_THT:R_Axial_DIN0204_L3.6mm_D1.6mm_P7.62mm_Horizontal | ~ | terminal4N
R6 | 1Meg | Resistor_THT:R_Axial_DIN0204_L3.6mm_D1.6mm_P7.62mm_Horizontal | ~ | terminal4N
R7 | 1Meg | Resistor_THT:R_Axial_DIN0204_L3.6mm_D1.6mm_P7.62mm_Horizontal | ~ | terminal4N
R8 | 1Meg | Resistor_THT:R_Axial_DIN0204_L3.6mm_D1.6mm_P7.62mm_Horizontal | ~ | terminal4N
R1 | 1Meg | Resistor_THT:R_Axial_DIN0204_L3.6mm_D1.6mm_P7.62mm_Horizontal | ~ | terminal4S
R2 | 1Meg | Resistor_THT:R_Axial_DIN0204_L3.6mm_D1.6mm_P7.62mm_Horizontal | ~ | terminal4S
R3 | 1Meg | Resistor_THT:R_Axial_DIN0204_L3.6mm_D1.6mm_P7.62mm_Horizontal | ~ | terminal4S
R4 | 1Meg | Resistor_THT:R_Axial_DIN0204_L3.6mm_D1.6mm_P7.62mm_Horizontal | ~ | terminal4S
R1 | 1Meg | Resistor_THT:R_Axial_DIN0204_L3.6mm_D1.6mm_P7.62mm_Horizontal | ~ | terminal1-2-3-6
R2 | 1Meg | Resistor_THT:R_Axial_DIN0204_L3.6mm_D1.6mm_P7.62mm_Horizontal | ~ | terminal1-2-3-6
R3 | 1Meg | Resistor_THT:R_Axial_DIN0204_L3.6mm_D1.6mm_P7.62mm_Horizontal | ~ | terminal1-2-3-6
R4 | 1Meg | Resistor_THT:R_Axial_DIN0204_L3.6mm_D1.6mm_P7.62mm_Horizontal | ~ | terminal1-2-3-6
R5 | 1Meg | Resistor_THT:R_Axial_DIN0204_L3.6mm_D1.6mm_P7.62mm_Horizontal | ~ | terminal1-2-3-6
R6 | 1Meg | Resistor_THT:R_Axial_DIN0204_L3.6mm_D1.6mm_P7.62mm_Horizontal | ~ | terminal1-2-3-6
R7 | 1Meg | Resistor_THT:R_Axial_DIN0204_L3.6mm_D1.6mm_P7.62mm_Horizontal | ~ | terminal1-2-3-6
R8 | 1Meg | Resistor_THT:R_Axial_DIN0204_L3.6mm_D1.6mm_P7.62mm_Horizontal | ~ | terminal1-2-3-6
R1 | 1Meg | Resistor_THT:R_Axial_DIN0204_L3.6mm_D1.6mm_P7.62mm_Horizontal | ~ | terminal1-2-3-6
R2 | 1Meg | Resistor_THT:R_Axial_DIN0204_L3.6mm_D1.6mm_P7.62mm_Horizontal | ~ | terminal1-2-3-6
R3 | 1Meg | Resistor_THT:R_Axial_DIN0204_L3.6mm_D1.6mm_P7.62mm_Horizontal | ~ | terminal1-2-3-6
R4 | 1Meg | Resistor_THT:R_Axial_DIN0204_L3.6mm_D1.6mm_P7.62mm_Horizontal | ~ | terminal1-2-3-6
R5 | 1Meg | Resistor_THT:R_Axial_DIN0204_L3.6mm_D1.6mm_P7.62mm_Horizontal | ~ | terminal1-2-3-6
R6 | 1Meg | Resistor_THT:R_Axial_DIN0204_L3.6mm_D1.6mm_P7.62mm_Horizontal | ~ | terminal1-2-3-6
R7 | 1Meg | Resistor_THT:R_Axial_DIN0204_L3.6mm_D1.6mm_P7.62mm_Horizontal | ~ | terminal1-2-3-6
R8 | 1Meg | Resistor_THT:R_Axial_DIN0204_L3.6mm_D1.6mm_P7.62mm_Horizontal | ~ | terminal1-2-3-6
R1 | 1Meg | Resistor_THT:R_Axial_DIN0204_L3.6mm_D1.6mm_P7.62mm_Horizontal | ~ | terminal1-2-3-6
R2 | 1Meg | Resistor_THT:R_Axial_DIN0204_L3.6mm_D1.6mm_P7.62mm_Horizontal | ~ | terminal1-2-3-6
R3 | 1Meg | Resistor_THT:R_Axial_DIN0204_L3.6mm_D1.6mm_P7.62mm_Horizontal | ~ | terminal1-2-3-6
R4 | 1Meg | Resistor_THT:R_Axial_DIN0204_L3.6mm_D1.6mm_P7.62mm_Horizontal | ~ | terminal1-2-3-6
R5 | 1Meg | Resistor_THT:R_Axial_DIN0204_L3.6mm_D1.6mm_P7.62mm_Horizontal | ~ | terminal1-2-3-6
R6 | 1Meg | Resistor_THT:R_Axial_DIN0204_L3.6mm_D1.6mm_P7.62mm_Horizontal | ~ | terminal1-2-3-6
R7 | 1Meg | Resistor_THT:R_Axial_DIN0204_L3.6mm_D1.6mm_P7.62mm_Horizontal | ~ | terminal1-2-3-6
R8 | 1Meg | Resistor_THT:R_Axial_DIN0204_L3.6mm_D1.6mm_P7.62mm_Horizontal | ~ | terminal1-2-3-6
R1 | 1Meg | Resistor_THT:R_Axial_DIN0204_L3.6mm_D1.6mm_P7.62mm_Horizontal | ~ | terminal1-2-3-6
R2 | 1Meg | Resistor_THT:R_Axial_DIN0204_L3.6mm_D1.6mm_P7.62mm_Horizontal | ~ | terminal1-2-3-6
R3 | 1Meg | Resistor_THT:R_Axial_DIN0204_L3.6mm_D1.6mm_P7.62mm_Horizontal | ~ | terminal1-2-3-6
R4 | 1Meg | Resistor_THT:R_Axial_DIN0204_L3.6mm_D1.6mm_P7.62mm_Horizontal | ~ | terminal1-2-3-6
R5 | 1Meg | Resistor_THT:R_Axial_DIN0204_L3.6mm_D1.6mm_P7.62mm_Horizontal | ~ | terminal1-2-3-6
R6 | 1Meg | Resistor_THT:R_Axial_DIN0204_L3.6mm_D1.6mm_P7.62mm_Horizontal | ~ | terminal1-2-3-6
R7 | 1Meg | Resistor_THT:R_Axial_DIN0204_L3.6mm_D1.6mm_P7.62mm_Horizontal | ~ | terminal1-2-3-6
R8 | 1Meg | Resistor_THT:R_Axial_DIN0204_L3.6mm_D1.6mm_P7.62mm_Horizontal | ~ | terminal1-2-3-6
R1 | 1Meg | Resistor_THT:R_Axial_DIN0204_L3.6mm_D1.6mm_P7.62mm_Horizontal | ~ | terminal1-2-3-6
R2 | 1Meg | Resistor_THT:R_Axial_DIN0204_L3.6mm_D1.6mm_P7.62mm_Horizontal | ~ | terminal1-2-3-6
R3 | 1Meg | Resistor_THT:R_Axial_DIN0204_L3.6mm_D1.6mm_P7.62mm_Horizontal | ~ | terminal1-2-3-6
R4 | 1Meg | Resistor_THT:R_Axial_DIN0204_L3.6mm_D1.6mm_P7.62mm_Horizontal | ~ | terminal1-2-3-6
R5 | 1Meg | Resistor_THT:R_Axial_DIN0204_L3.6mm_D1.6mm_P7.62mm_Horizontal | ~ | terminal1-2-3-6
R6 | 1Meg | Resistor_THT:R_Axial_DIN0204_L3.6mm_D1.6mm_P7.62mm_Horizontal | ~ | terminal1-2-3-6
R7 | 1Meg | Resistor_THT:R_Axial_DIN0204_L3.6mm_D1.6mm_P7.62mm_Horizontal | ~ | terminal1-2-3-6
R8 | 1Meg | Resistor_THT:R_Axial_DIN0204_L3.6mm_D1.6mm_P7.62mm_Horizontal | ~ | terminal1-2-3-6
D3 | 1N4007 | Diode_THT:D_DO-41_SOD81_P2.54mm_Vertical_AnodeUp | http://www.vishay.com/docs/88503/1n4001.pdf | Mother
D2 | 1SS178 | Diode_THT:D_DO-35_SOD27_P2.54mm_Vertical_AnodeUp | ~ | Mother
R10 | 4.7k | Resistor_THT:R_Axial_DIN0204_L3.6mm_D1.6mm_P7.62mm_Horizontal | ~ | Display
R9 | 4.7k | Resistor_THT:R_Axial_DIN0204_L3.6mm_D1.6mm_P7.62mm_Horizontal | ~ | Display
RV5 | 50kA |  | ~ | peripheral
RV4 | 50KB |  | ~ | peripheral
RV3 | 50KB |  | ~ | peripheral
RV2 | 50KB |  | ~ | peripheral
RV1 | 50KB |  | ~ | peripheral
U1 | 74HC00 | Package_DIP:DIP-14_W7.62mm | http://www.ti.com/lit/gpn/sn74hc00 | Mother
U2 | 74HC00 | Package_DIP:DIP-14_W7.62mm | http://www.ti.com/lit/gpn/sn74hc00 | terminal4N
J12 | AudioJack2 |  | ~ | peripheral
J11 | AudioJack2 |  | ~ | peripheral
J10 | AudioJack3_SwitchTR |  | ~ | peripheral
J6 | AudioJack3_SwitchTR |  | ~ | peripheral
U2 | BP5293-33 | Package_TO_SOT_THT:TO-220-3_Vertical | https://akizukidenshi.com/download/ds/rohm/BP5293_DataSheet_J_VerC_161013.pdf | Mother
U3 | BP5293-50 | Package_TO_SOT_THT:TO-220-3_Vertical | https://akizukidenshi.com/download/ds/rohm/BP5293_DataSheet_J_VerC_161013.pdf | Mother
J7 | Conn_01x02_Female |  | ~ | peripheral
J18 | Conn_01x02_Female |  | ~ | peripheral
J31 | Conn_01x02_Female |  | ~ | peripheral
J38 | Conn_01x02_Female |  | ~ | peripheral
J45 | Conn_01x02_Female |  | ~ | peripheral
J16 | Conn_01x02_Female |  | ~ | peripheral
J30 | Conn_01x02_Female |  | ~ | peripheral
J36 | Conn_01x02_Female |  | ~ | peripheral
J4 | Conn_01x02_Female |  | ~ | peripheral
J8 | Conn_01x02_Female |  | ~ | peripheral
J24 | Conn_01x02_Female |  | ~ | peripheral
J3 | Conn_01x02_Male | Connector_PinHeader_2.54mm:PinHeader_1x02_P2.54mm_Horizontal | ~ | fader
J1 | Conn_01x02_Male | Connector_PinHeader_2.54mm:PinHeader_1x02_P2.54mm_Horizontal | ~ | Mother
J3 | Conn_01x02_Male | Connector_PinHeader_2.54mm:PinHeader_1x02_P2.54mm_Horizontal | ~ | terminal5
J3 | Conn_01x02_Male | Connector_PinHeader_2.54mm:PinHeader_1x02_P2.54mm_Horizontal | ~ | terminal7
J3 | Conn_01x02_Male | Connector_PinHeader_2.54mm:PinHeader_1x02_P2.54mm_Horizontal | ~ | terminal4N
J3 | Conn_01x02_Male | Connector_PinHeader_2.54mm:PinHeader_1x02_P2.54mm_Horizontal | ~ | terminal4S
J3 | Conn_01x02_Male | Connector_PinHeader_2.54mm:PinHeader_1x02_P2.54mm_Horizontal | ~ | terminal1-2-3-6
J3 | Conn_01x02_Male | Connector_PinHeader_2.54mm:PinHeader_1x02_P2.54mm_Horizontal | ~ | terminal1-2-3-6
J3 | Conn_01x02_Male | Connector_PinHeader_2.54mm:PinHeader_1x02_P2.54mm_Horizontal | ~ | terminal1-2-3-6
J3 | Conn_01x02_Male | Connector_PinHeader_2.54mm:PinHeader_1x02_P2.54mm_Horizontal | ~ | terminal1-2-3-6
J3 | Conn_01x02_Male | Connector_PinHeader_2.54mm:PinHeader_1x02_P2.54mm_Horizontal | ~ | terminal1-2-3-6
J20 | Conn_01x04_Female |  | ~ | peripheral
J23 | Conn_01x04_Female |  | ~ | peripheral
J2 | Conn_01x04_Male | Connector_PinHeader_2.54mm:PinHeader_1x04_P2.54mm_Horizontal | ~ | Display
J4 | Conn_01x04_Male | Connector_PinHeader_2.54mm:PinHeader_1x04_P2.54mm_Horizontal | ~ | Mother
J2 | Conn_01x05_Female |  | ~ | peripheral
J15 | Conn_01x05_Female |  | ~ | peripheral
J27 | Conn_01x05_Female |  | ~ | peripheral
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

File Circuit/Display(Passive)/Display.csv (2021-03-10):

Reference | Value | Footprint | Datasheet | Display
AFF4 | LTS-6960HR | Display_7Segment:7SegmentLED_LTS6760_LTS6780 | https://datasheet.octopart.com/LTS-6960HR-Lite-On-datasheet-11803242.pdf | Display
D4 | LED | LED_THT:LED_D3.0mm | ~ | Display
D3 | LED | LED_THT:LED_D3.0mm | ~ | Display
D2 | LED | LED_THT:LED_D3.0mm | ~ | Display
AFF5 | LTS-6960HR | Display_7Segment:7SegmentLED_LTS6760_LTS6780 | https://datasheet.octopart.com/LTS-6960HR-Lite-On-datasheet-11803242.pdf | Display
AFF3 | LTS-6960HR | Display_7Segment:7SegmentLED_LTS6760_LTS6780 | https://datasheet.octopart.com/LTS-6960HR-Lite-On-datasheet-11803242.pdf | Display
AFF2 | LTS-6960HR | Display_7Segment:7SegmentLED_LTS6760_LTS6780 | https://datasheet.octopart.com/LTS-6960HR-Lite-On-datasheet-11803242.pdf | Display
AFF1 | LTS-6960HR | Display_7Segment:7SegmentLED_LTS6760_LTS6780 | https://datasheet.octopart.com/LTS-6960HR-Lite-On-datasheet-11803242.pdf | Display
C4 | 10u | Capacitor_THT:CP_Radial_D5.0mm_P2.50mm | ~ | Display
C2 | 0.1u | Capacitor_THT:C_Disc_D3.0mm_W1.6mm_P2.50mm | ~ | Display
C3 | 0.01u | Capacitor_THT:C_Disc_D3.0mm_W2.0mm_P2.50mm | ~ | Display
C1 | 0.1u | Capacitor_THT:C_Disc_D3.0mm_W1.6mm_P2.50mm | ~ | Display
R1 | 220 | Resistor_THT:R_Axial_DIN0204_L3.6mm_D1.6mm_P7.62mm_Horizontal | ~ | Display
R8 | 10k | Resistor_THT:R_Axial_DIN0204_L3.6mm_D1.6mm_P7.62mm_Horizontal | ~ | Display
R10 | 4.7k | Resistor_THT:R_Axial_DIN0204_L3.6mm_D1.6mm_P7.62mm_Horizontal | ~ | Display
U3 | ULN2803A | Package_DIP:DIP-18_W7.62mm | http://www.ti.com/lit/ds/symlink/uln2803a.pdf | Display
U1 | TBD62783A | Package_DIP:DIP-18_W7.62mm | http://toshiba.semicon-storage.com/info/docget.jsp?did=30523&prodName=TBD62783APG | Display
BAR1 | HDSP-4830_2 | Display:HDSP-4830 | https://docs.broadcom.com/docs/AV02-1798EN | Display
D1 | LED | LED_THT:LED_D3.0mm | ~ | Display
J1 | Conn_PIC_ICSP_ICD | Connector_PinHeader_2.54mm:PinHeader_1x06_P2.54mm_Horizontal | http://ww1.microchip.com/downloads/en/devicedoc/30277d.pdf | Display
R9 | 4.7k | Resistor_THT:R_Axial_DIN0204_L3.6mm_D1.6mm_P7.62mm_Horizontal | ~ | Display
U2 | PIC16F18854-SO | Package_DIP:DIP-28_W7.62mm | http://ww1.microchip.com/downloads/en/DeviceDoc/PIC16(L)F18854%20Data%20Sheet_DS40001826C.pdf | Display
R7 | 220 | Resistor_THT:R_Axial_DIN0204_L3.6mm_D1.6mm_P7.62mm_Horizontal | ~ | Display
R6 | 220 | Resistor_THT:R_Axial_DIN0204_L3.6mm_D1.6mm_P7.62mm_Horizontal | ~ | Display
R5 | 220 | Resistor_THT:R_Axial_DIN0204_L3.6mm_D1.6mm_P7.62mm_Horizontal | ~ | Display
R4 | 220 | Resistor_THT:R_Axial_DIN0204_L3.6mm_D1.6mm_P7.62mm_Horizontal | ~ | Display
R3 | 220 | Resistor_THT:R_Axial_DIN0204_L3.6mm_D1.6mm_P7.62mm_Horizontal | ~ | Display
R2 | 220 | Resistor_THT:R_Axial_DIN0204_L3.6mm_D1.6mm_P7.62mm_Horizontal | ~ | Display
J2 | Conn_01x04_Female | Connector_PinHeader_2.54mm:PinHeader_1x04_P2.54mm_Horizontal | ~ | Display

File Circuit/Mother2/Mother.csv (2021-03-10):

Reference | Value | Footprint | Datasheet | Component Link 1 Description | Component Link 1 URL | Component Link 3 Description | Component Link 3 URL | Component Link 4 Description | Component Link 4 URL | Datasheet Version | Mounting Technology | Package Description | Package Version | category | ciiva ids | imported | library id | manufacturer | package | release date | vault revision | Mother
R3 | 1k | Resistor_THT:R_Axial_DIN0204_L3.6mm_D1.6mm_P7.62mm_Horizontal | ~ | Mother
U4 | PIC32MX110F016B-I_SP | Package_DIP:DIP-28_W7.62mm | http://ww1.microchip.com/downloads/en/DeviceDoc/61168E.pdf | Manufacturer URL | http://www.microchip.com | Package Specification | http://www.microchip.com/stellent/groups/techpub_sg/documents/packagingspec/en012702.pdf | Product URL | http://www.microchip.com/PIC32MX110F016B | Rev. E | Through Hole | 28-Lead Plastic Dual In-Line, 34.86 x 6.79 mm Body, 2.54 mm Pitch | C04-070B | IC | 1156563 | yes | fa7413a09ebb98f6 | Microchip | SPDIP-SP28 | 1359970709 | E7E3DC04-7D64-40B1-9461-E4D614E67543 | Mother
J6 | Conn_PIC_ICSP_ICD | Connector_PinHeader_2.54mm:PinHeader_1x06_P2.54mm_Horizontal | http://ww1.microchip.com/downloads/en/devicedoc/30277d.pdf | Mother
C22 | 10uF | Capacitor_THT:C_Disc_D5.0mm_W2.5mm_P5.00mm | ~ | Mother
C10 | 0.1u | Capacitor_THT:C_Disc_D3.0mm_W1.6mm_P2.50mm | ~ | Mother
C11 | 0.1u | Capacitor_THT:C_Disc_D3.0mm_W1.6mm_P2.50mm | ~ | Mother
C6 | 0.1u | Capacitor_THT:C_Disc_D3.0mm_W1.6mm_P2.50mm | ~ | Mother
R2 | 10k | Resistor_THT:R_Axial_DIN0204_L3.6mm_D1.6mm_P7.62mm_Horizontal | ~ | Mother
U5 | 4051 | Package_DIP:DIP-16_W7.62mm | http://www.intersil.com/content/dam/Intersil/documents/cd40/cd4051bms-52bms-53bms.pdf | Mother
C20 | 0.1u | Capacitor_THT:C_Disc_D3.0mm_W1.6mm_P2.50mm | ~ | Mother
C19 | 0.1u | Capacitor_THT:C_Disc_D3.0mm_W1.6mm_P2.50mm | ~ | Mother
C18 | 0.1u | Capacitor_THT:C_Disc_D3.0mm_W1.6mm_P2.50mm | ~ | Mother
C17 | 0.1u | Capacitor_THT:C_Disc_D3.0mm_W1.6mm_P2.50mm | ~ | Mother
C16 | 0.1u | Capacitor_THT:C_Disc_D3.0mm_W1.6mm_P2.50mm | ~ | Mother
C15 | 0.1u | Capacitor_THT:C_Disc_D3.0mm_W1.6mm_P2.50mm | ~ | Mother
C14 | 0.1u | Capacitor_THT:C_Disc_D3.0mm_W1.6mm_P2.50mm | ~ | Mother
C12 | 0.1u | Capacitor_THT:C_Disc_D3.0mm_W1.6mm_P2.50mm | ~ | Mother
R12 | 10k | Resistor_THT:R_Axial_DIN0204_L3.6mm_D1.6mm_P7.62mm_Horizontal | ~ | Mother
R13 | 10k | Resistor_THT:R_Axial_DIN0204_L3.6mm_D1.6mm_P7.62mm_Horizontal | ~ | Mother
R14 | 10k | Resistor_THT:R_Axial_DIN0204_L3.6mm_D1.6mm_P7.62mm_Horizontal | ~ | Mother
R15 | 10k | Resistor_THT:R_Axial_DIN0204_L3.6mm_D1.6mm_P7.62mm_Horizontal | ~ | Mother
R16 | 10k | Resistor_THT:R_Axial_DIN0204_L3.6mm_D1.6mm_P7.62mm_Horizontal | ~ | Mother
R17 | 10k | Resistor_THT:R_Axial_DIN0204_L3.6mm_D1.6mm_P7.62mm_Horizontal | ~ | Mother
R18 | 10k | Resistor_THT:R_Axial_DIN0204_L3.6mm_D1.6mm_P7.62mm_Horizontal | ~ | Mother
R19 | 10k | Resistor_THT:R_Axial_DIN0204_L3.6mm_D1.6mm_P7.62mm_Horizontal | ~ | Mother
J3 | Conn_02x09_Odd_Even | Connector_PinHeader_2.54mm:PinHeader_2x09_P2.54mm_Horizontal | ~ | Mother
R4 | 10k | Resistor_THT:R_Axial_DIN0204_L3.6mm_D1.6mm_P7.62mm_Horizontal | ~ | Mother
R5 | 10k | Resistor_THT:R_Axial_DIN0204_L3.6mm_D1.6mm_P7.62mm_Horizontal | ~ | Mother
R6 | 10k | Resistor_THT:R_Axial_DIN0204_L3.6mm_D1.6mm_P7.62mm_Horizontal | ~ | Mother
R7 | 10k | Resistor_THT:R_Axial_DIN0204_L3.6mm_D1.6mm_P7.62mm_Horizontal | ~ | Mother
R8 | 10k | Resistor_THT:R_Axial_DIN0204_L3.6mm_D1.6mm_P7.62mm_Horizontal | ~ | Mother
R9 | 10k | Resistor_THT:R_Axial_DIN0204_L3.6mm_D1.6mm_P7.62mm_Horizontal | ~ | Mother
R10 | 10k | Resistor_THT:R_Axial_DIN0204_L3.6mm_D1.6mm_P7.62mm_Horizontal | ~ | Mother
R11 | 10k | Resistor_THT:R_Axial_DIN0204_L3.6mm_D1.6mm_P7.62mm_Horizontal | ~ | Mother
U6 | TLP785 | Package_DIP:DIP-4_W7.62mm | https://toshiba.semicon-storage.com/info/docget.jsp?did=10569&prodName=TLP785 | Mother
R21 | 220 | Resistor_THT:R_Axial_DIN0204_L3.6mm_D1.6mm_P7.62mm_Horizontal | ~ | Mother
D2 | 1SS178 | Diode_THT:D_DO-35_SOD27_P2.54mm_Vertical_AnodeUp | ~ | Mother
R20 | 220 | Resistor_THT:R_Axial_DIN0204_L3.6mm_D1.6mm_P7.62mm_Horizontal | ~ | Mother
U1 | 74HC00 | Package_DIP:DIP-14_W7.62mm | http://www.ti.com/lit/gpn/sn74hc00 | Mother
R22 | 220 | Resistor_THT:R_Axial_DIN0204_L3.6mm_D1.6mm_P7.62mm_Horizontal | ~ | Mother
R23 | 220 | Resistor_THT:R_Axial_DIN0204_L3.6mm_D1.6mm_P7.62mm_Horizontal | ~ | Mother
C1 | 0.1u | Capacitor_THT:C_Disc_D3.0mm_W1.6mm_P2.50mm | ~ | Mother
J2 | Conn_01x05_Male | Connector_PinHeader_2.54mm:PinHeader_1x05_P2.54mm_Horizontal | ~ | Mother
C7 | 10u | Capacitor_THT:CP_Radial_D5.0mm_P2.50mm | ~ | Mother
J7 | Conn_01x05_Male | Connector_PinHeader_2.54mm:PinHeader_1x05_P2.54mm_Horizontal | ~ | Mother
U3 | BP5293-50 | Package_TO_SOT_THT:TO-220-3_Vertical | https://akizukidenshi.com/download/ds/rohm/BP5293_DataSheet_J_VerC_161013.pdf | Mother
U2 | BP5293-33 | Package_TO_SOT_THT:TO-220-3_Vertical | https://akizukidenshi.com/download/ds/rohm/BP5293_DataSheet_J_VerC_161013.pdf | Mother
C2 | 10u | Capacitor_THT:CP_Radial_D5.0mm_P2.50mm | ~ | Mother
C3 | 10u | Capacitor_THT:CP_Radial_D5.0mm_P2.50mm | ~ | Mother
R1 | 1k | Resistor_THT:R_Axial_DIN0204_L3.6mm_D1.6mm_P7.62mm_Horizontal | ~ | Mother
D1 | LED | LED_THT:LED_D3.0mm | ~ | Mother
C9 | 10u | Capacitor_THT:CP_Radial_D5.0mm_P2.50mm | ~ | Mother
C4 | 10u | Capacitor_THT:CP_Radial_D5.0mm_P2.50mm | ~ | Mother
C5 | 0.1u | Capacitor_THT:C_Disc_D3.0mm_W1.6mm_P2.50mm | ~ | Mother
C8 | 0.1u | Capacitor_THT:C_Disc_D3.0mm_W1.6mm_P2.50mm | ~ | Mother
F1 | RXEF050 | Capacitor_THT:C_Disc_D8.0mm_W2.5mm_P5.00mm | https://akizukidenshi.com/download/ds/tyco/rxef050.pdf | Mother
J4 | Conn_01x04_Male | Connector_PinHeader_2.54mm:PinHeader_1x04_P2.54mm_Horizontal | ~ | Mother
C21 | 10u | Capacitor_THT:C_Axial_L5.1mm_D3.1mm_P7.50mm_Horizontal | ~ | Mother
J1 | Conn_01x02_Male | Connector_PinHeader_2.54mm:PinHeader_1x02_P2.54mm_Horizontal | ~ | Mother
J5 | Conn_02x09_Odd_Even | Connector_PinHeader_2.54mm:PinHeader_2x09_P2.54mm_Horizontal | ~ | Mother
D3 | 1N4007 | Diode_THT:D_DO-41_SOD81_P2.54mm_Vertical_AnodeUp | http://www.vishay.com/docs/88503/1n4001.pdf | Mother

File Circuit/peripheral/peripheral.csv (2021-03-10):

Reference | Value | Footprint | Datasheet | peripheral
J9 | Conn_02x08_Odd_Even |  | ~ | peripheral
MK1 | Piezo |  | ~ | peripheral
MK2 | Piezo |  | ~ | peripheral
MK4 | Piezo |  | ~ | peripheral
MK6 | Piezo |  | ~ | peripheral
MK8 | Piezo |  | ~ | peripheral
MK10 | Piezo |  | ~ | peripheral
MK11 | Piezo |  | ~ | peripheral
MK12 | Piezo |  | ~ | peripheral
J19 | Conn_02x08_Odd_Even |  | ~ | peripheral
MK15 | Piezo |  | ~ | peripheral
MK17 | Piezo |  | ~ | peripheral
MK19 | Piezo |  | ~ | peripheral
MK21 | Piezo |  | ~ | peripheral
MK23 | Piezo |  | ~ | peripheral
MK25 | Piezo |  | ~ | peripheral
MK26 | Piezo |  | ~ | peripheral
MK27 | Piezo |  | ~ | peripheral
J32 | Conn_02x08_Odd_Even |  | ~ | peripheral
MK31 | Piezo |  | ~ | peripheral
MK33 | Piezo |  | ~ | peripheral
MK35 | Piezo |  | ~ | peripheral
MK37 | Piezo |  | ~ | peripheral
MK39 | Piezo |  | ~ | peripheral
MK41 | Piezo |  | ~ | peripheral
MK42 | Piezo |  | ~ | peripheral
MK43 | Piezo |  | ~ | peripheral
J40 | Conn_02x08_Odd_Even |  | ~ | peripheral
MK47 | Piezo |  | ~ | peripheral
MK49 | Piezo |  | ~ | peripheral
MK51 | Piezo |  | ~ | peripheral
MK53 | Piezo |  | ~ | peripheral
MK54 | Piezo |  | ~ | peripheral
MK55 | Piezo |  | ~ | peripheral
MK56 | Piezo |  | ~ | peripheral
MK57 | Piezo |  | ~ | peripheral
J46 | Conn_02x08_Odd_Even |  | ~ | peripheral
MK58 | Piezo |  | ~ | peripheral
MK59 | Piezo |  | ~ | peripheral
MK60 | Piezo |  | ~ | peripheral
MK61 | Piezo |  | ~ | peripheral
J44 | DB15_Female |  | ~ | peripheral
J2 | Conn_01x05_Female |  | ~ | peripheral
J7 | Conn_01x02_Female |  | ~ | peripheral
J15 | Conn_01x05_Female |  | ~ | peripheral
J18 | Conn_01x02_Female |  | ~ | peripheral
J27 | Conn_01x05_Female |  | ~ | peripheral
J31 | Conn_01x02_Female |  | ~ | peripheral
J34 | Conn_01x05_Female |  | ~ | peripheral
J38 | Conn_01x02_Female |  | ~ | peripheral
J43 | Conn_01x05_Female |  | ~ | peripheral
J45 | Conn_01x02_Female |  | ~ | peripheral
J1 | Conn_01x05_Female |  | ~ | peripheral
J13 | Conn_01x05_Female |  | ~ | peripheral
J16 | Conn_01x02_Female |  | ~ | peripheral
J25 | Conn_01x05_Female |  | ~ | peripheral
J30 | Conn_01x02_Female |  | ~ | peripheral
J33 | Conn_01x05_Female |  | ~ | peripheral
J36 | Conn_01x02_Female |  | ~ | peripheral
J4 | Conn_01x02_Female |  | ~ | peripheral
J12 | AudioJack2 |  | ~ | peripheral
RV4 | 50KB |  | ~ | peripheral
SW1 | SW_Panel |  | ~ | peripheral
J26 | DIN-5_180degree |  | http://www.mouser.com/ds/2/18/40_c091_abd_e-75918.pdf | peripheral
J22 | DIN-5_180degree |  | http://www.mouser.com/ds/2/18/40_c091_abd_e-75918.pdf | peripheral
J28 | Jack-DC |  | ~ | peripheral
J3 | Conn_01x05_Female |  | ~ | peripheral
J8 | Conn_01x02_Female |  | ~ | peripheral
J14 | Conn_02x09_Odd_Even |  | ~ | peripheral
J37 | Conn_02x08_Odd_Even |  | ~ | peripheral
MK28 | Piezo |  | ~ | peripheral
MK29 | Piezo |  | ~ | peripheral
MK40 | Piezo |  | ~ | peripheral
MK38 | Piezo |  | ~ | peripheral
MK36 | Piezo |  | ~ | peripheral
MK34 | Piezo |  | ~ | peripheral
MK32 | Piezo |  | ~ | peripheral
MK30 | Piezo |  | ~ | peripheral
J29 | Conn_02x08_Odd_Even |  | ~ | peripheral
MK24 | Piezo |  | ~ | peripheral
MK22 | Piezo |  | ~ | peripheral
MK20 | Piezo |  | ~ | peripheral
MK18 | Piezo |  | ~ | peripheral
MK16 | Piezo |  | ~ | peripheral
MK14 | Piezo |  | ~ | peripheral
MK13 | Piezo |  | ~ | peripheral
J17 | Conn_02x08_Odd_Even |  | ~ | peripheral
MK9 | Piezo |  | ~ | peripheral
MK7 | Piezo |  | ~ | peripheral
MK5 | Piezo |  | ~ | peripheral
MK3 | Piezo |  | ~ | peripheral
J5 | Conn_02x08_Odd_Even |  | ~ | peripheral
MK52 | Piezo |  | ~ | peripheral
MK50 | Piezo |  | ~ | peripheral
MK48 | Piezo |  | ~ | peripheral
MK46 | Piezo |  | ~ | peripheral
MK45 | Piezo |  | ~ | peripheral
MK44 | Piezo |  | ~ | peripheral
RV5 | 50kA |  | ~ | peripheral
J11 | AudioJack2 |  | ~ | peripheral
J10 | AudioJack3_SwitchTR |  | ~ | peripheral
J6 | AudioJack3_SwitchTR |  | ~ | peripheral
RV3 | 50KB |  | ~ | peripheral
RV2 | 50KB |  | ~ | peripheral
RV1 | 50KB |  | ~ | peripheral
J20 | Conn_01x04_Female |  | ~ | peripheral
J23 | Conn_01x04_Female |  | ~ | peripheral
J39 | Conn_02x09_Odd_Even |  | ~ | peripheral
SW2 | SW_Panel |  | ~ | peripheral
SW3 | SW_Panel |  | ~ | peripheral
SW4 | SW_Panel |  | ~ | peripheral
SW5 | SW_Panel |  | ~ | peripheral
SW6 | SW_Panel |  | ~ | peripheral
SW7 | SW_Panel |  | ~ | peripheral
SW8 | SW_Panel |  | ~ | peripheral
J35 | Conn_01x05_Female |  | ~ | peripheral
J21 | Conn_01x05_Female |  | ~ | peripheral
J24 | Conn_01x02_Female |  | ~ | peripheral
J42 | Conn_02x09_Odd_Even |  | ~ | peripheral
J41 | DB15_Male |  | ~ | peripheral

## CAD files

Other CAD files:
Hardware/NE_controll_panel.FCStd
Hardware/NW_controll_panel.FCStd

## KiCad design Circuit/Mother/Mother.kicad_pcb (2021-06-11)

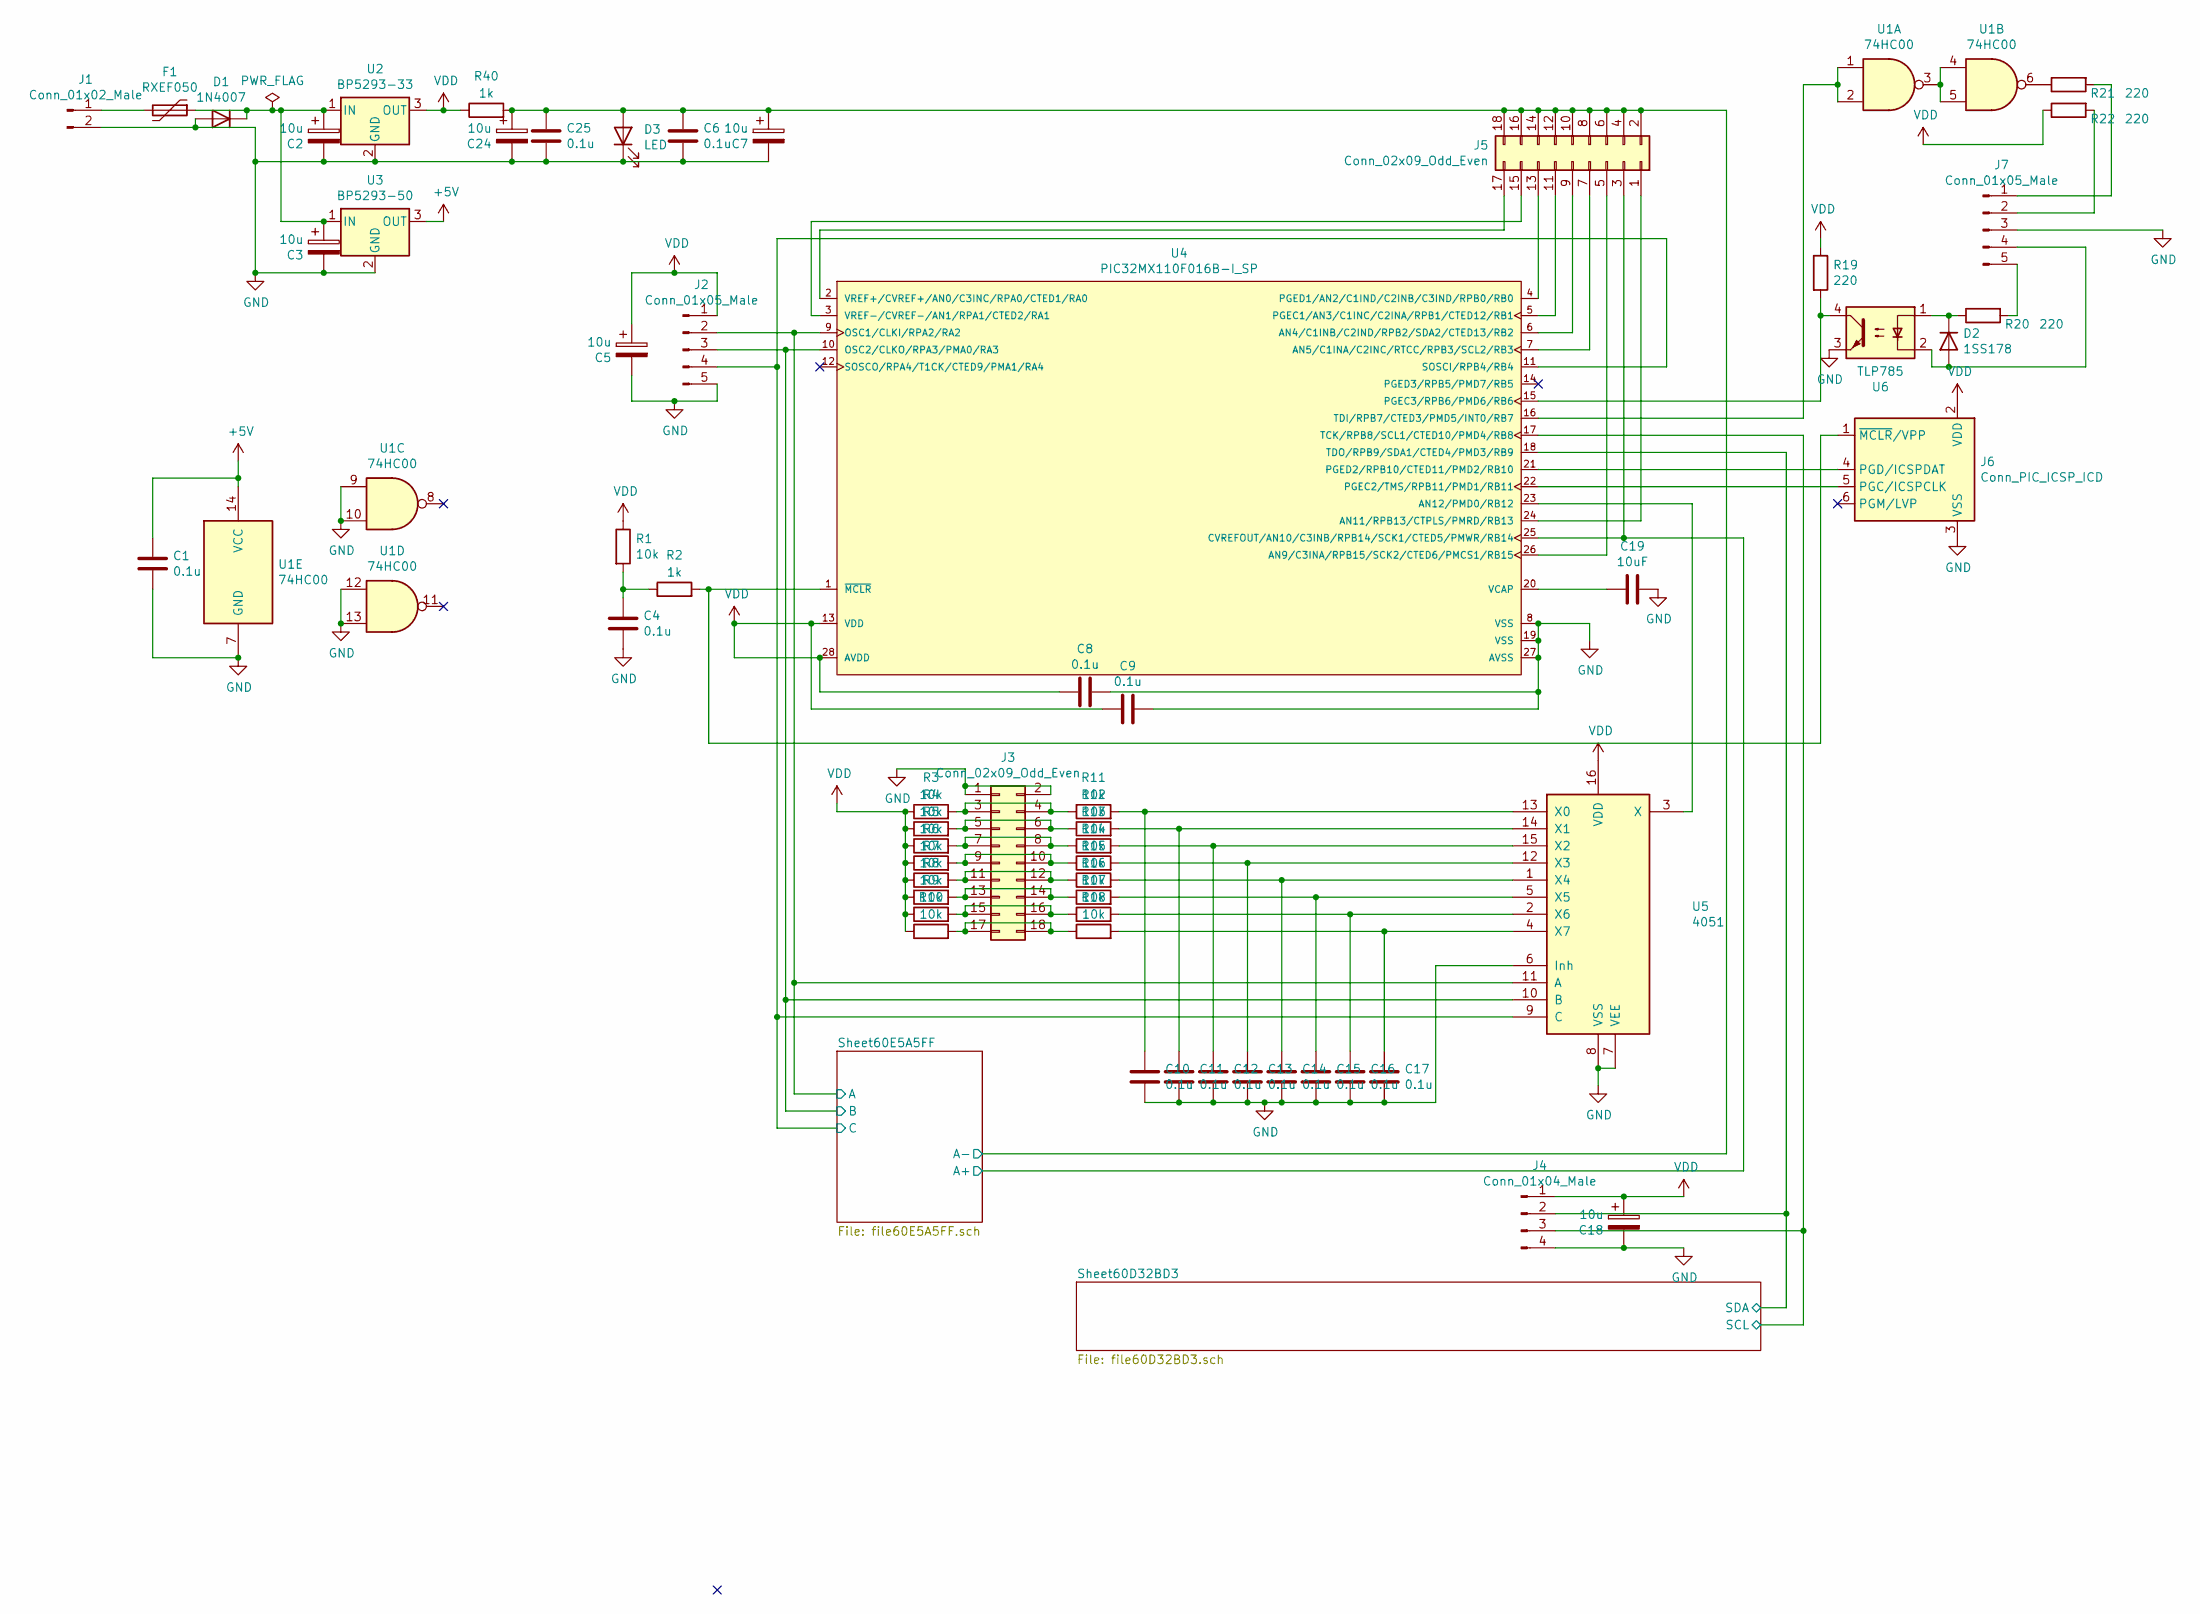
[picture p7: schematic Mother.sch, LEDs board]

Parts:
C1, C4, C6, C8, C9, C10, C11, C12, C13, C14, C15, C16, C17, C25: 0.1u; C_Disc_D3.0mm_W1.6mm_P2.50mm
C2, C3, C5, C7, C24: 10u; CP_Radial_D5.0mm_P2.50mm
C18: 10u; C_Axial_L5.1mm_D3.1mm_P7.50mm_Horizontal
C19: 10uF; C_Disc_D5.0mm_W2.5mm_P5.00mm
D1: 1N4007; D_DO-41_SOD81_P2.54mm_Vertical_AnodeUp
D2: 1SS178; D_DO-35_SOD27_P2.54mm_Vertical_AnodeUp
D3: LED; LED_D5.0mm
F1: RXEF050; C_Disc_D8.0mm_W2.5mm_P5.00mm
J1: Conn_01x02_Male; PinHeader_1x02_P2.54mm_Horizontal
J2, J7: Conn_01x05_Male; PinHeader_1x05_P2.54mm_Horizontal
J3, J5: Conn_02x09_Odd_Even; PinHeader_2x09_P2.54mm_Horizontal
J4: Conn_01x04_Male; PinHeader_1x04_P2.54mm_Horizontal
J6: Conn_PIC_ICSP_ICD; PinHeader_1x06_P2.54mm_Horizontal
R1, R3, R4, R5, R6, R7, R8, R9, R10, R11, R12, R13, R14, R15, R16, R17, R18: 10k; R_Axial_DIN0204_L3.6mm_D1.6mm_P7.62mm_Horizontal
R2, R40: 1k; R_Axial_DIN0204_L3.6mm_D1.6mm_P7.62mm_Horizontal
R19, R20, R21, R22: 220; R_Axial_DIN0204_L3.6mm_D1.6mm_P7.62mm_Horizontal
U1: 74HC00; DIP-14_W7.62mm
U2: BP5293-33; TO-220-3_Vertical
U3: BP5293-50; TO-220-3_Vertical
U4: PIC32MX110F016B-I_SP; DIP-28_W7.62mm
U5: 4051; DIP-16_W7.62mm
U6: TLP785; DIP-4_W7.62mm

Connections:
+5V: C1.2, U1.14 (VCC), U3.3 (OUT)
/Sheet60D32BD3/SCL: J4.3, U4.17 (TCK/RPB8/SCL1/CTED10/PMD4/RB8); also elsewhere on the board
/Sheet60D32BD3/SDA: J4.2, U4.18 (TDO/RPB9/SDA1/CTED4/PMD3/RB9); also elsewhere on the board
/Sheet60E5A5FF/A: J2.2, U4.9 (OSC1/CLKI/RPA2/RA2), U5.11 (A); also elsewhere on the board
/Sheet60E5A5FF/A+: J5.3, U4.25 (CVREFOUT/AN10/C3INB/RPB14/SCK1/CTED5/PM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); also elsewhere on the board
/Sheet60E5A5FF/A-: C6.2, C7.1, C24.1, C25.2, D3.2 (A), J5.2, J5.4, J5.6, J5.8, J5.10, J5.12, J5.14, J5.16, J5.18, R40.2; also elsewhere on the board
/Sheet60E5A5FF/B: J2.3, U4.10 (OSC2/CLKO/RPA3/PMA0/RA3), U5.10 (B); also elsewhere on the board
/Sheet60E5A5FF/C: J2.4, U4.11 (SOSCI/RPB4/RB4), U5.9 (C); also elsewhere on the board
GND: C1.1, C2.2, C3.2, C4.1, C5.2, C6.1, C7.2, C8.1, C9.1, C10.1, C11.1, C12.1, C13.1, C14.1, C15.1, C16.1, C17.1, C18.2, C19.1, C24.2, C25.1, D1.2 (A), D3.1 (K), J1.2, J2.5, J3.1, J3.2, J4.4, J6.3 (VSS), J7.3, U1.7 (GND), U1.9, U1.10, U1.12, U1.13, U2.2 (GND), U3.2 (GND), U4.8 (VSS), U4.19 (VSS), U4.27 (AVSS), U5.6 (Inh), U5.7 (VEE), U5.8 (VSS), U6.3; also elsewhere on the board
unnamed: C2.1, C3.1, D1.1 (K), F1.1, U2.1 (IN), U3.1 (IN)
unnamed: C4.2, R1.2, R2.1
unnamed: C10.2, R11.2, U5.13 (X0)
unnamed: C11.2, R12.2, U5.14 (X1)
unnamed: C12.2, R13.2, U5.15 (X2)
unnamed: C13.2, R14.2, U5.12 (X3)
unnamed: C14.2, R15.2, U5.1 (X4)
unnamed: C15.2, R16.2, U5.5 (X5)
unnamed: C16.2, R17.2, U5.2 (X6)
unnamed: C17.2, R18.2, U5.4 (X7)
unnamed: C19.2, U4.20 (VCAP)
unnamed: D2.1 (K), R20.1, U6.1
unnamed: D2.2 (A), J7.4, U6.2
unnamed: F1.2, J1.1
unnamed: J3.3, J3.4, R3.2, R11.1
unnamed: J3.5, J3.6, R4.2, R12.1
unnamed: J3.7, J3.8, R5.2, R13.1
unnamed: J3.9, J3.10, R6.2, R14.1
unnamed: J3.11, J3.12, R7.2, R15.1
unnamed: J3.13, J3.14, R8.2, R16.1
unnamed: J3.15, J3.16, R9.2, R17.1
unnamed: J3.17, J3.18, R10.2, R18.1
unnamed: J5.1, U4.24 (AN11/RPB13/CTPLS/PMRD/RB13)
unnamed: J5.5, U4.26 (AN9/C3INA/RPB15/SCK2/CTED6/PMCS1/RB15)
unnamed: J5.7, U4.7 (AN5/C1INA/C2INC/RTCC/RPB3/SCL2/RB3)
unnamed: J5.9, U4.6 (AN4/C1INB/C2IND/RPB2/SDA2/CTED13/RB2)
unnamed: J5.11, U4.5 (PGEC1/AN3/C1INC/C2INA/RPB1/CTED12/RB1)
unnamed: J5.13, U4.4 (PGED1/AN2/C1IND/C2INB/C3IND/RPB0/RB0)
unnamed: J5.15, U4.3 (VREF-/CVREF-/AN1/RPA1/CTED2/RA1)
unnamed: J5.17, U4.2 (VREF+/CVREF+/AN0/C3INC/RPA0/CTED1/RA0)
unnamed: J6.1 (~MCLR~/VPP), R2.2, U4.1 (~MCLR~)
unnamed: J6.4 (PGD/ICSPDAT), U4.21 (PGED2/RPB10/CTED11/PMD2/RB10)
unnamed: J6.5 (PGC/ICSPCLK), U4.22 (PGEC2/TMS/RPB11/PMD1/RB11)
unnamed: J7.1, R21.2
unnamed: J7.2, R22.2
unnamed: J7.5, R20.2
unnamed: R19.2, U4.15 (PGEC3/RPB6/PMD6/RB6), U6.4
unnamed: R21.1, U1.6
unnamed: U1.1, U1.2, U4.16 (TDI/RPB7/CTED3/PMD5/INT0/RB7)
unnamed: U1.3, U1.4, U1.5
unnamed: U4.23 (AN12/PMD0/RB12), U5.3 (X)
VDD: C5.1, C8.2, C9.2, C18.1, J2.1, J4.1, J6.2 (VDD), R1.1, R3.1, R4.1, R5.1, R6.1, R7.1, R8.1, R9.1, R10.1, R19.1, R22.1, R40.1, U2.3 (OUT), U4.13 (VDD), U4.28 (AVDD), U5.16 (VDD); also elsewhere on the board

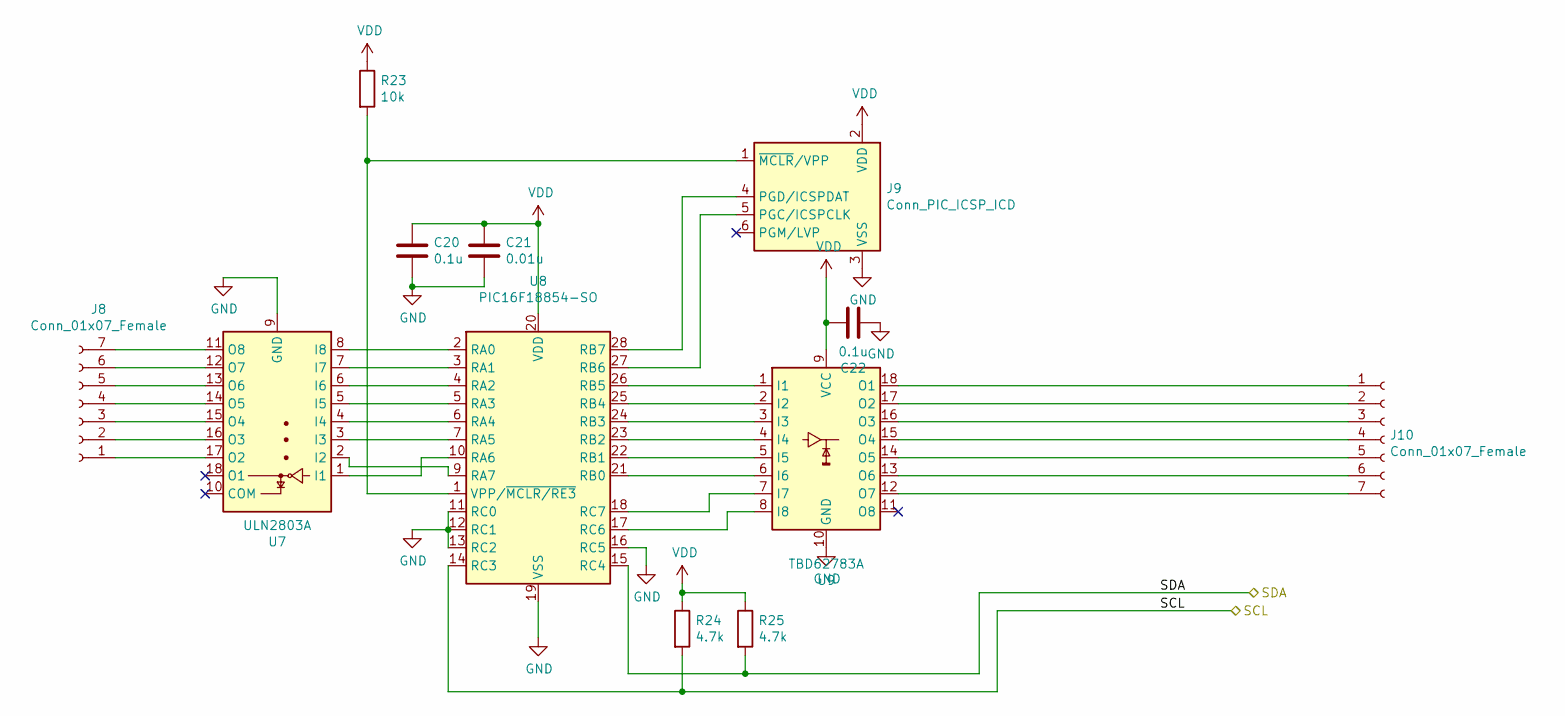
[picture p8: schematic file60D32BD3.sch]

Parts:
C20, C22: 0.1u; C_Disc_D3.0mm_W1.6mm_P2.50mm
C21: 0.01u; C_Disc_D3.0mm_W2.0mm_P2.50mm
J8, J10: Conn_01x07_Female; PinSocket_1x07_P2.54mm_Vertical
J9: Conn_PIC_ICSP_ICD; PinHeader_1x06_P2.54mm_Horizontal
R23: 10k; R_Axial_DIN0204_L3.6mm_D1.6mm_P7.62mm_Horizontal
R24, R25: 4.7k; R_Axial_DIN0204_L3.6mm_D1.6mm_P7.62mm_Horizontal
U7: ULN2803A; DIP-18_W7.62mm
U8: PIC16F18854-SO; DIP-28_W7.62mm
U9: TBD62783A; DIP-18_W7.62mm

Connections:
/Sheet60D32BD3/SCL: R24.2, U8.14 (RC3); also elsewhere on the board
/Sheet60D32BD3/SDA: R25.2, U8.15 (RC4); also elsewhere on the board
GND: C20.1, C21.1, C22.2, J9.3 (VSS), U7.9 (GND), U8.8 (VSS), U8.11 (RC0), U8.12 (RC1), U8.13 (RC2), U8.16 (RC5), U8.19 (VSS), U9.10 (GND); also elsewhere on the board
unnamed: J8.1, U7.17 (O2)
unnamed: J8.2, U7.16 (O3)
unnamed: J8.3, U7.15 (O4)
unnamed: J8.4, U7.14 (O5)
unnamed: J8.5, U7.13 (O6)
unnamed: J8.6, U7.12 (O7)
unnamed: J8.7, U7.11 (O8)
unnamed: J9.1 (~MCLR~/VPP), R23.2, U8.1 (VPP/~MCLR/RE3)
unnamed: J9.4 (PGD/ICSPDAT), U8.28 (RB7)
unnamed: J9.5 (PGC/ICSPCLK), U8.27 (RB6)
unnamed: J10.1, U9.18 (O1)
unnamed: J10.2, U9.17 (O2)
unnamed: J10.3, U9.16 (O3)
unnamed: J10.4, U9.15 (O4)
unnamed: J10.5, U9.14 (O5)
unnamed: J10.6, U9.13 (O6)
unnamed: J10.7, U9.12 (O7)
unnamed: U7.1 (I1), U8.10 (RA6)
unnamed: U7.2 (I2), U8.9 (RA7)
unnamed: U7.3 (I3), U8.7 (RA5)
unnamed: U7.4 (I4), U8.6 (RA4)
unnamed: U7.5 (I5), U8.5 (RA3)
unnamed: U7.6 (I6), U8.4 (RA2)
unnamed: U7.7 (I7), U8.3 (RA1)
unnamed: U7.8 (I8), U8.2 (RA0)
unnamed: U8.17 (RC6), U9.8 (I8)
unnamed: U8.18 (RC7), U9.7 (I7)
unnamed: U8.21 (RB0), U9.6 (I6)
unnamed: U8.22 (RB1), U9.5 (I5)
unnamed: U8.23 (RB2), U9.4 (I4)
unnamed: U8.24 (RB3), U9.3 (I3)
unnamed: U8.25 (RB4), U9.2 (I2)
unnamed: U8.26 (RB5), U9.1 (I1)
VDD: C20.2, C21.2, C22.1, J9.2 (VDD), R23.1, R24.1, R25.1, U8.20 (VDD), U9.9 (VCC); also elsewhere on the board

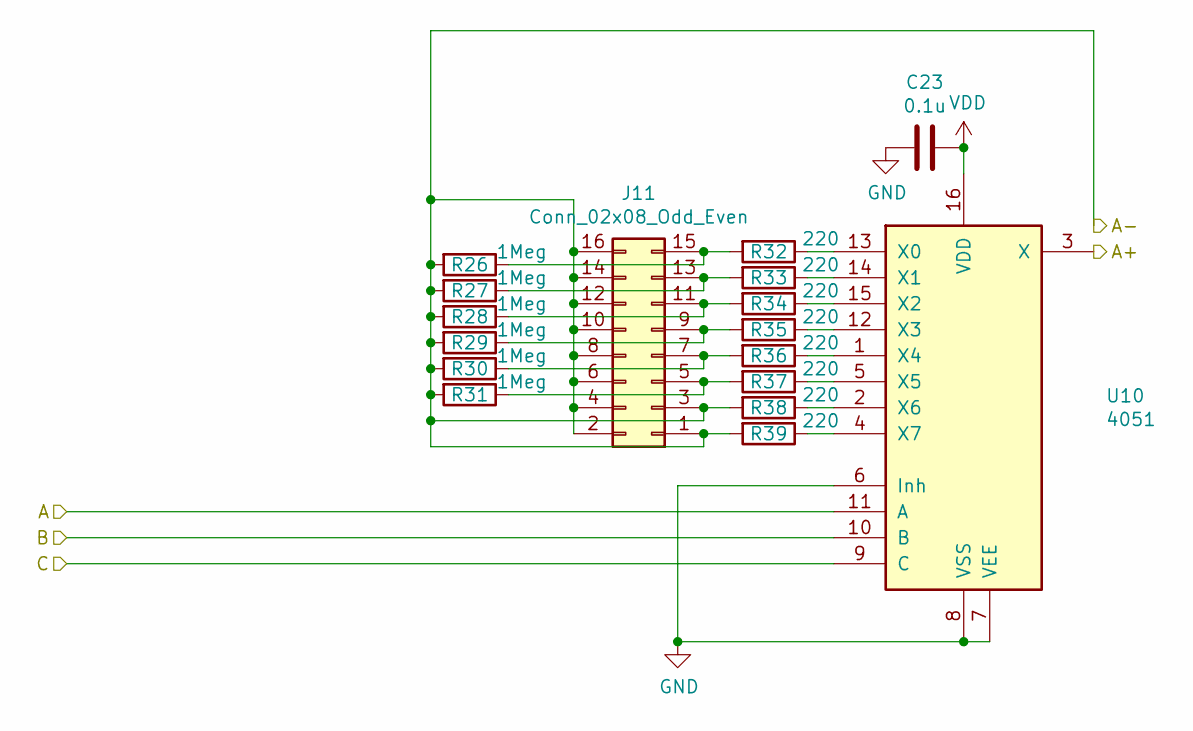
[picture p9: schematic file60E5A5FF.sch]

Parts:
C23: 0.1u; C_Disc_D3.0mm_W1.6mm_P2.50mm
J11: Conn_02x08_Odd_Even; PinHeader_2x08_P2.54mm_Horizontal
R26, R27, R28, R29, R30, R31: 1Meg; R_Axial_DIN0204_L3.6mm_D1.6mm_P7.62mm_Horizontal
R32, R33, R34, R35, R36, R37, R38, R39: 220; R_Axial_DIN0204_L3.6mm_D1.6mm_P7.62mm_Horizontal
U10: 4051; DIP-16_W7.62mm

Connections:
/Sheet60E5A5FF/A: U10.11 (A); also elsewhere on the board
/Sheet60E5A5FF/A+: U10.3 (X); also elsewhere on the board
/Sheet60E5A5FF/A-: J11.1, J11.2, J11.3, J11.4, J11.6, J11.8, J11.10, J11.12, J11.14, J11.16, R26.2, R27.2, R28.2, R29.2, R30.2, R31.2, R38.2, R39.2; also elsewhere on the board
/Sheet60E5A5FF/B: U10.10 (B); also elsewhere on the board
/Sheet60E5A5FF/C: U10.9 (C); also elsewhere on the board
GND: C23.2, U10.6 (Inh), U10.7 (VEE), U10.8 (VSS); also elsewhere on the board
unnamed: J11.5, R31.1, R37.2
unnamed: J11.7, R30.1, R36.2
unnamed: J11.9, R29.1, R35.2
unnamed: J11.11, R28.1, R34.2
unnamed: J11.13, R27.1, R33.2
unnamed: J11.15, R26.1, R32.2
unnamed: R32.1, U10.13 (X0)
unnamed: R33.1, U10.14 (X1)
unnamed: R34.1, U10.15 (X2)
unnamed: R35.1, U10.12 (X3)
unnamed: R36.1, U10.1 (X4)
unnamed: R37.1, U10.5 (X5)
unnamed: R38.1, U10.2 (X6)
unnamed: R39.1, U10.4 (X7)
VDD: C23.1, U10.16 (VDD); also elsewhere on the board

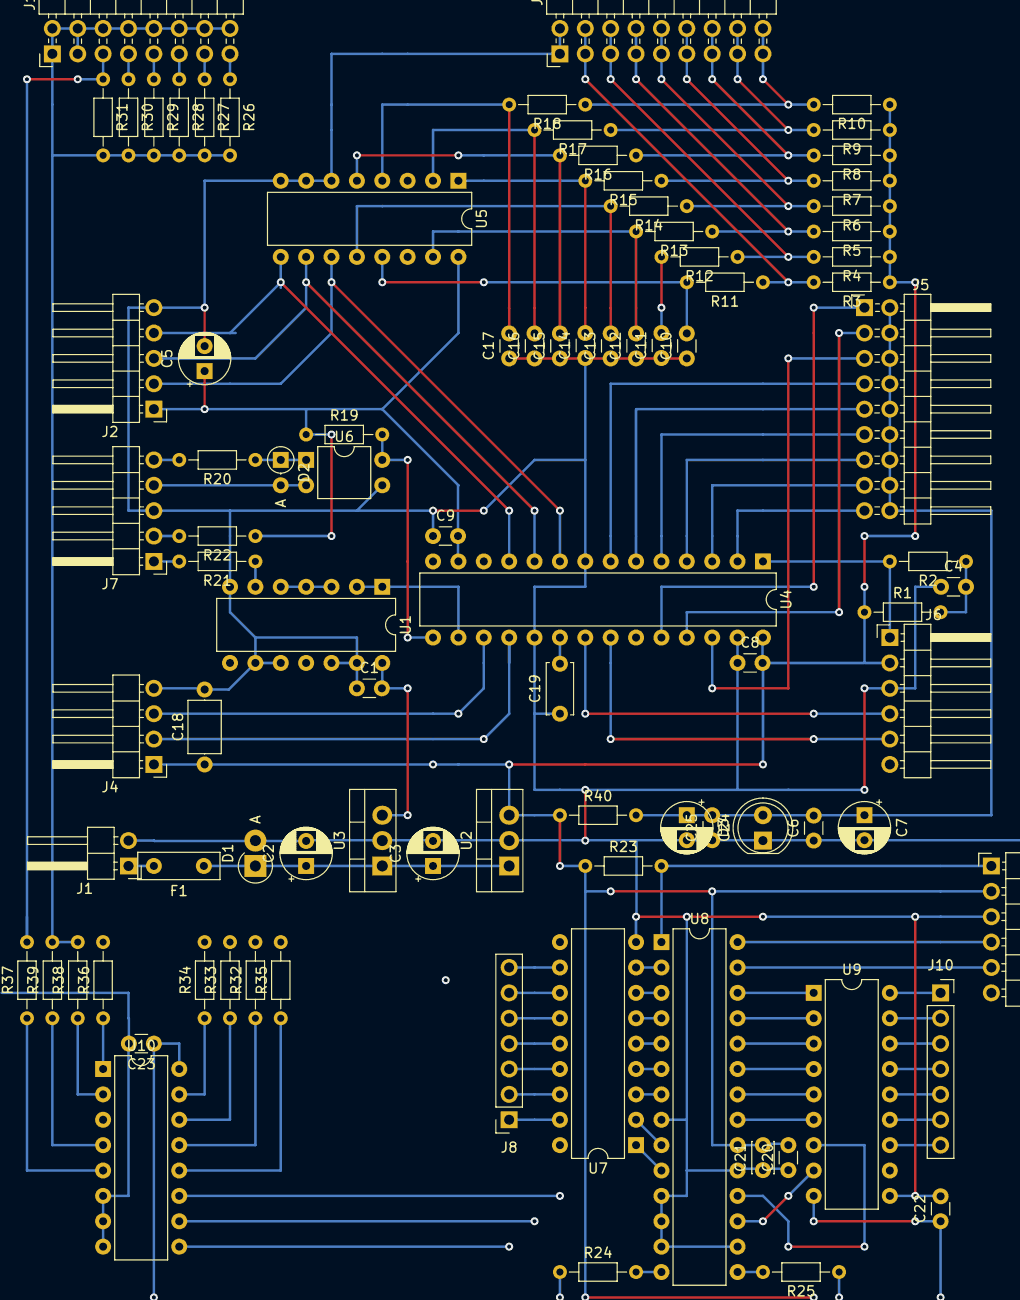
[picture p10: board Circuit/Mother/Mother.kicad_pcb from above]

Board: 4 copper layers, 90 parts (0 on the bottom side), 98 nets.

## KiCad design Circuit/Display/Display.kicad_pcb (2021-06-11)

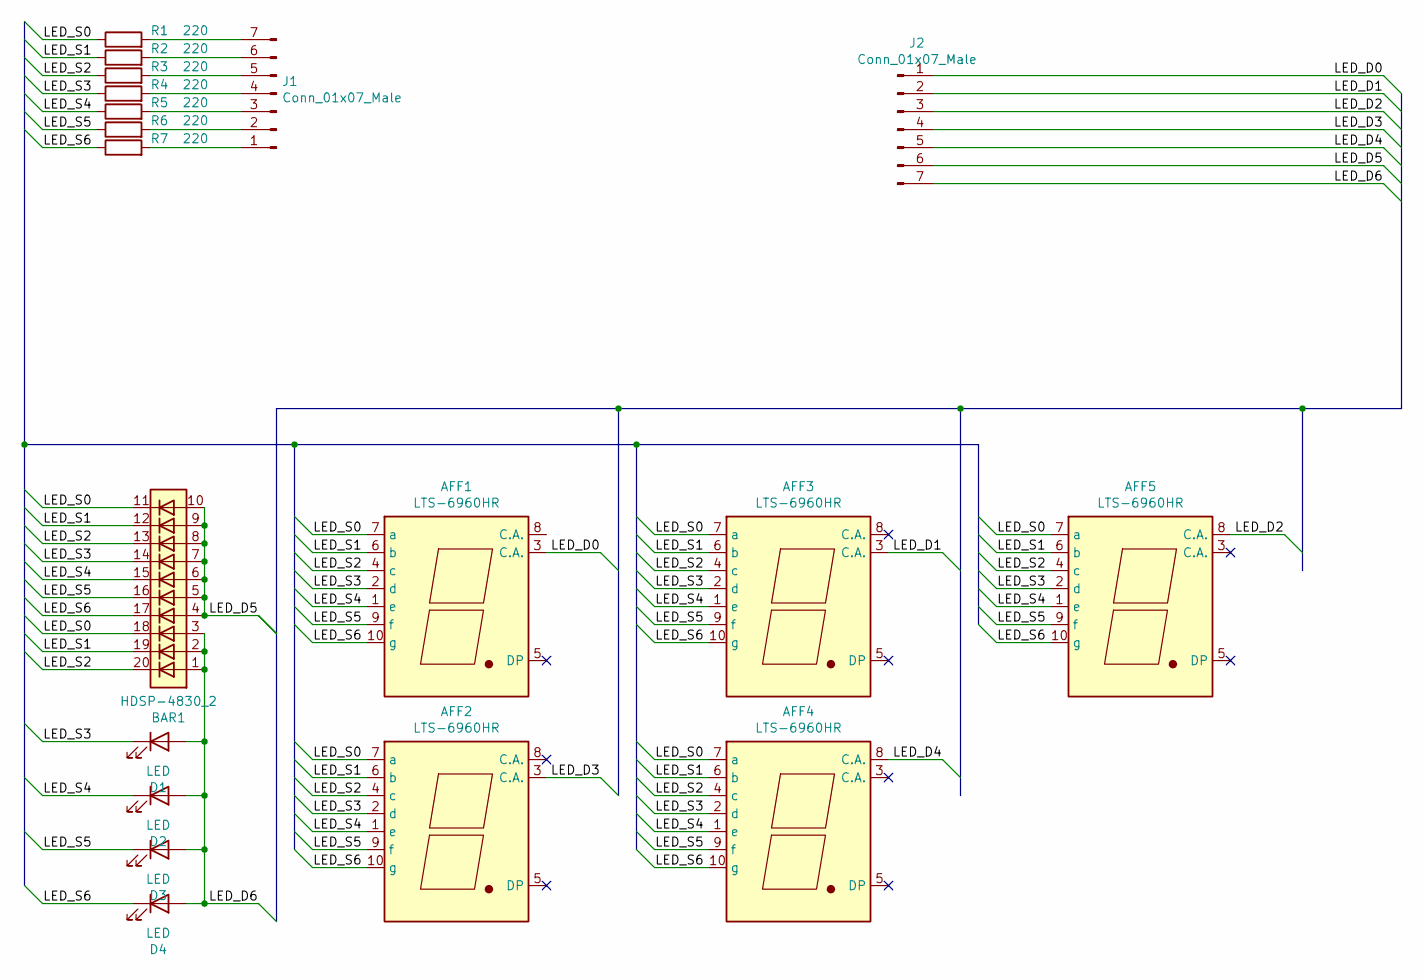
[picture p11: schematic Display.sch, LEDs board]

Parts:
AFF1, AFF2, AFF3, AFF4, AFF5: LTS-6960HR; 7SegmentLED_LTS6760_LTS6780
BAR1: HDSP-4830_2; HDSP-4830
D1, D2, D3, D4: LED; LED_D3.0mm
J1, J2: Conn_01x07_Male; PinHeader_1x07_P2.54mm_Vertical
R1, R2, R3, R4, R5, R6, R7: 220; R_Axial_DIN0204_L3.6mm_D1.6mm_P7.62mm_Horizontal

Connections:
/LED_D0: AFF1.3 (C.A.), J2.1
/LED_D1: AFF3.3 (C.A.), J2.2
/LED_D2: AFF5.8 (C.A.), J2.3
/LED_D3: AFF2.3 (C.A.), J2.4
/LED_D4: AFF4.8 (C.A.), J2.5
/LED_D5: BAR1.4 (A), BAR1.5 (A), BAR1.6 (A), BAR1.7 (A), BAR1.8 (A), BAR1.9 (A), BAR1.10 (A), J2.6
/LED_D6: BAR1.1 (A), BAR1.2 (A), BAR1.3 (A), D1.2 (A), D2.2 (A), D3.2 (A), D4.2 (A), J2.7
/LED_S0: AFF1.7 (a), AFF2.7 (a), AFF3.7 (a), AFF4.7 (a), AFF5.7 (a), BAR1.11 (K), BAR1.18 (K), R1.1
/LED_S1: AFF1.6 (b), AFF2.6 (b), AFF3.6 (b), AFF4.6 (b), AFF5.6 (b), BAR1.12 (K), BAR1.19 (K), R2.1
/LED_S2: AFF1.4 (c), AFF2.4 (c), AFF3.4 (c), AFF4.4 (c), AFF5.4 (c), BAR1.13 (K), BAR1.20 (K), R3.1
/LED_S3: AFF1.2 (d), AFF2.2 (d), AFF3.2 (d), AFF4.2 (d), AFF5.2 (d), BAR1.14 (K), D1.1 (K), R4.1
/LED_S4: AFF1.1 (e), AFF2.1 (e), AFF3.1 (e), AFF4.1 (e), AFF5.1 (e), BAR1.15 (K), D2.1 (K), R5.1
/LED_S5: AFF1.9 (f), AFF2.9 (f), AFF3.9 (f), AFF4.9 (f), AFF5.9 (f), BAR1.16 (K), D3.1 (K), R6.1
/LED_S6: AFF1.10 (g), AFF2.10 (g), AFF3.10 (g), AFF4.10 (g), AFF5.10 (g), BAR1.17 (K), D4.1 (K), R7.1
unnamed: J1.1, R7.2
unnamed: J1.2, R6.2
unnamed: J1.3, R5.2
unnamed: J1.4, R4.2
unnamed: J1.5, R3.2
unnamed: J1.6, R2.2
unnamed: J1.7, R1.2

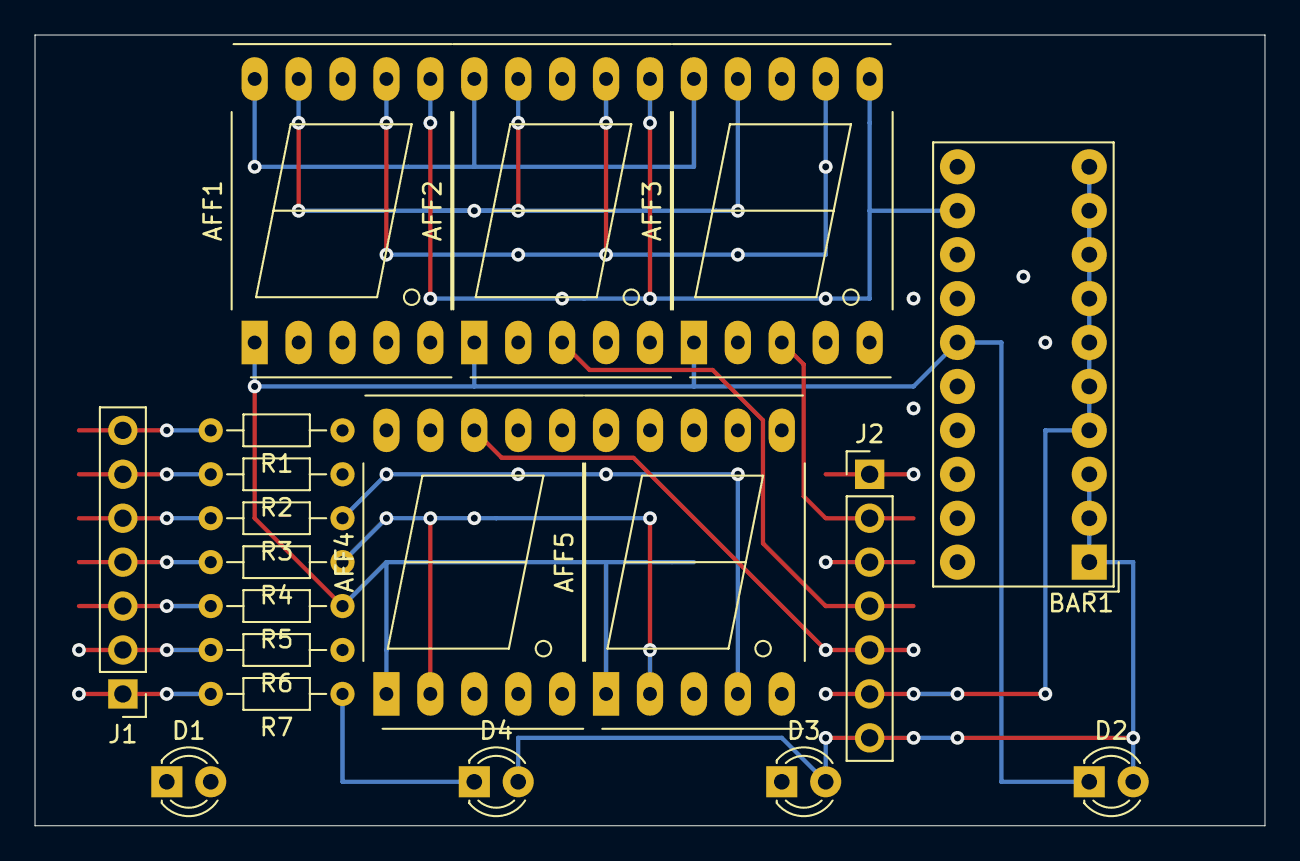
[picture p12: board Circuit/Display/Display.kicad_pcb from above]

Board: 4 copper layers, 71.1 x 45.7 mm, 19 parts (0 on the bottom side), 21 nets.

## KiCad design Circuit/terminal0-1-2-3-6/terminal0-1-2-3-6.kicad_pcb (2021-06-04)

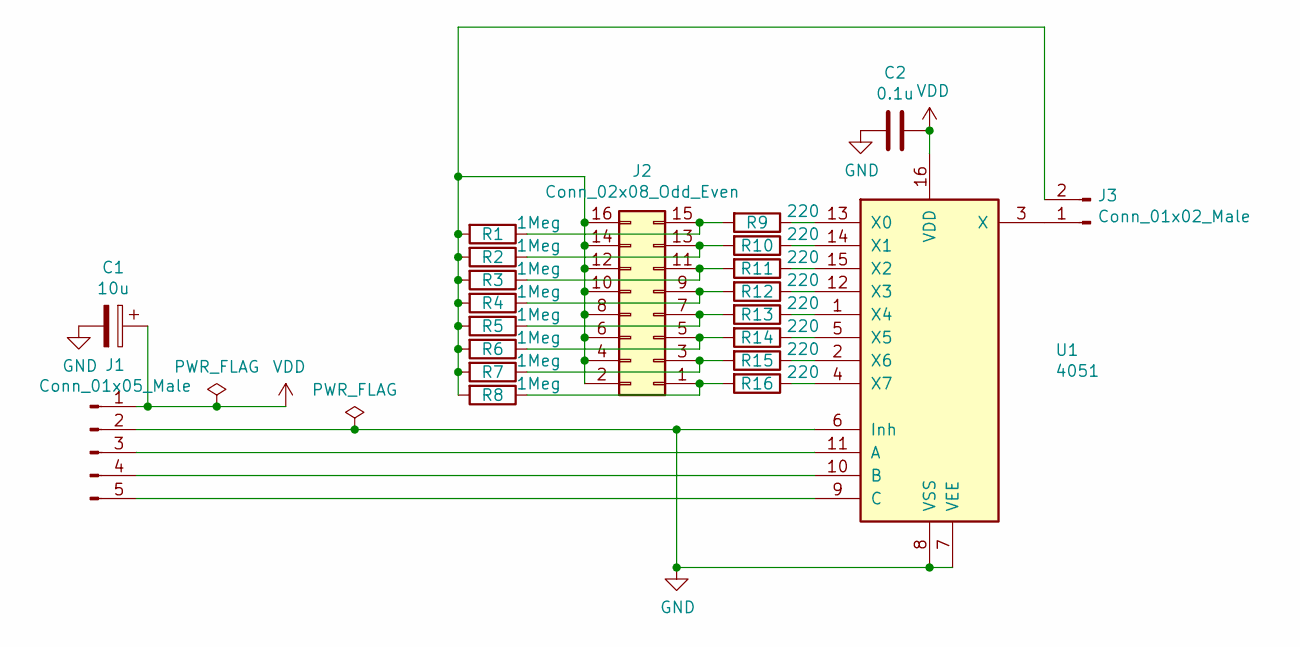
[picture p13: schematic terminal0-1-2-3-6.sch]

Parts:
C1: 10u; CP_Radial_D5.0mm_P2.50mm
C2: 0.1u; C_Disc_D3.0mm_W1.6mm_P2.50mm
J1: Conn_01x05_Male; PinHeader_1x05_P2.54mm_Horizontal
J2: Conn_02x08_Odd_Even; PinHeader_2x08_P2.54mm_Horizontal
J3: Conn_01x02_Male; PinHeader_1x02_P2.54mm_Horizontal
R1, R2, R3, R4, R5, R6, R7, R8: 1Meg; R_Axial_DIN0204_L3.6mm_D1.6mm_P7.62mm_Horizontal
R9, R10, R11, R12, R13, R14, R15, R16: 220; R_Axial_DIN0204_L3.6mm_D1.6mm_P7.62mm_Horizontal
U1: 4051; DIP-16_W7.62mm

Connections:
GND: C1.2, C2.2, J1.2, U1.6 (Inh), U1.7 (VEE), U1.8 (VSS)
unnamed: J1.3, U1.11 (A)
unnamed: J1.4, U1.10 (B)
unnamed: J1.5, U1.9 (C)
unnamed: J2.1, R8.1, R16.2
unnamed: J2.3, R7.1, R15.2
unnamed: J2.5, R6.1, R14.2
unnamed: J2.7, R5.1, R13.2
unnamed: J2.9, R4.1, R12.2
unnamed: J2.2, J2.4, J2.6, J2.8, J2.10, J2.12, J2.14, J2.16, J3.2, R1.2, R2.2, R3.2, R4.2, R5.2, R6.2, R7.2, R8.2
unnamed: J2.11, R3.1, R11.2
unnamed: J2.13, R2.1, R10.2
unnamed: J2.15, R1.1, R9.2
unnamed: J3.1, U1.3 (X)
unnamed: R9.1, U1.13 (X0)
unnamed: R10.1, U1.14 (X1)
unnamed: R11.1, U1.15 (X2)
unnamed: R12.1, U1.12 (X3)
unnamed: R13.1, U1.1 (X4)
unnamed: R14.1, U1.5 (X5)
unnamed: R15.1, U1.2 (X6)
unnamed: R16.1, U1.4 (X7)
VDD: C1.1, C2.1, J1.1, U1.16 (VDD)

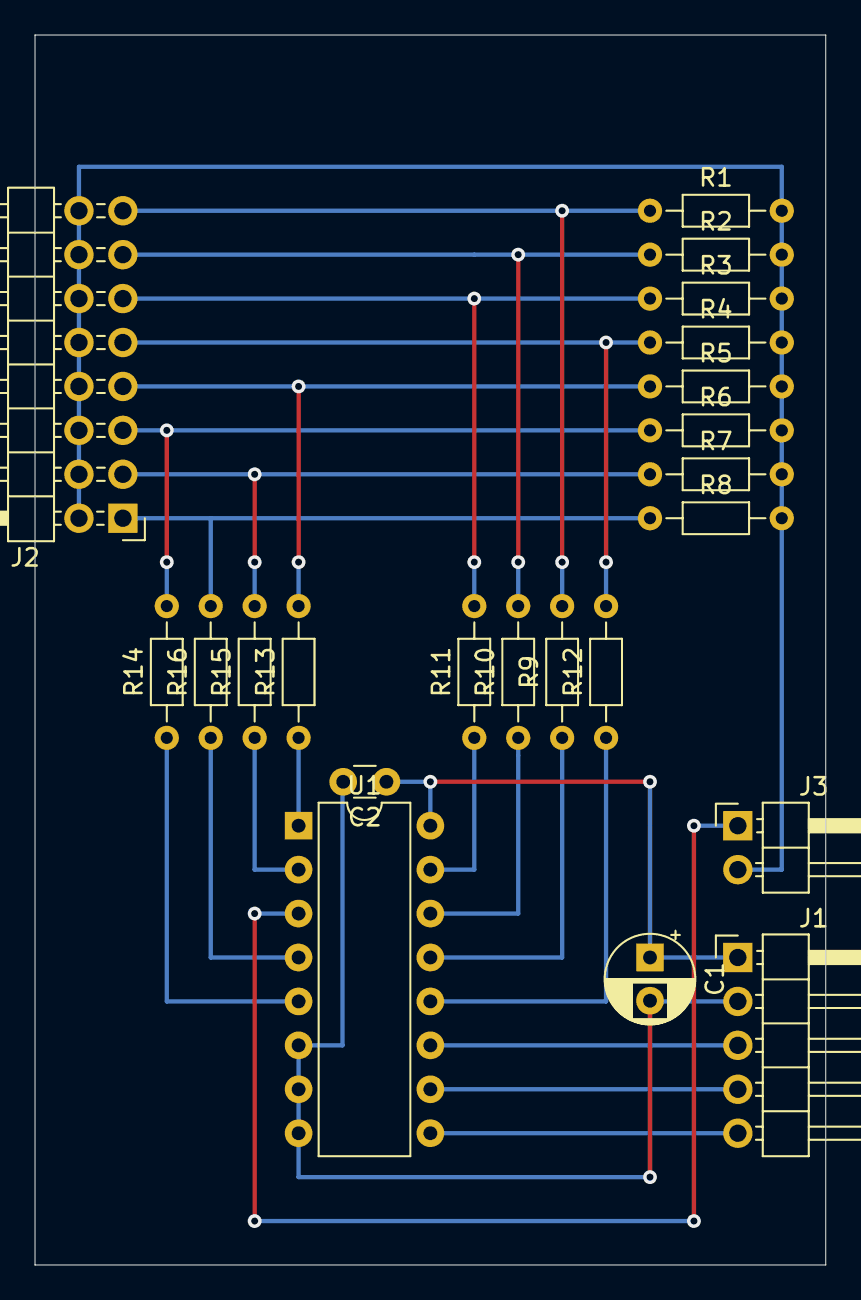
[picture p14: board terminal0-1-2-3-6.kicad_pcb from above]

Board: 2 copper layers, 45.7 x 71.1 mm, 22 parts (0 on the bottom side), 23 nets.

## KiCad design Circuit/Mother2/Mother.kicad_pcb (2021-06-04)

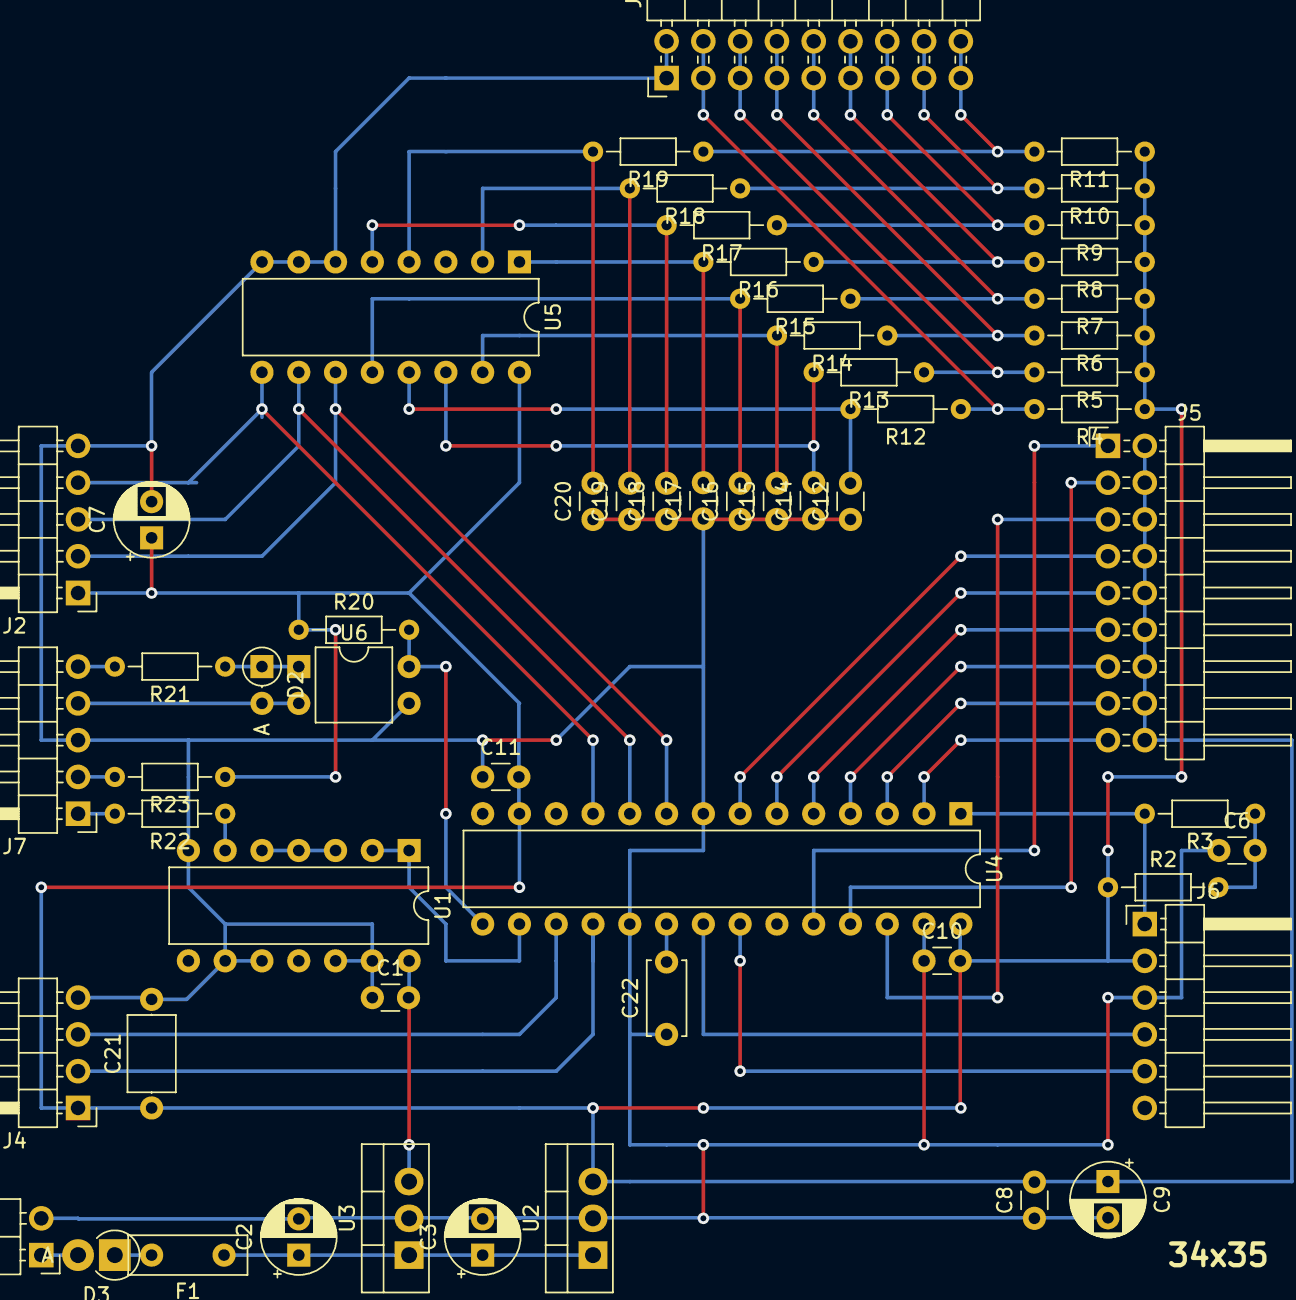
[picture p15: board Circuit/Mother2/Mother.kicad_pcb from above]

Board: 4 copper layers, 57 parts (0 on the bottom side), 51 nets.

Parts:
C1, C6, C8, C10, C11, C12, C14, C15, C16, C17, C18, C19, C20: 0.1u; C_Disc_D3.0mm_W1.6mm_P2.50mm
C2, C3, C7, C9: 10u; CP_Radial_D5.0mm_P2.50mm
C21: 10u; C_Axial_L5.1mm_D3.1mm_P7.50mm_Horizontal
C22: 10uF; C_Disc_D5.0mm_W2.5mm_P5.00mm
D2: 1SS178; D_DO-35_SOD27_P2.54mm_Vertical_AnodeUp
D3: 1N4007; D_DO-41_SOD81_P2.54mm_Vertical_AnodeUp
F1: RXEF050; C_Disc_D8.0mm_W2.5mm_P5.00mm
J1: Conn_01x02_Male; PinHeader_1x02_P2.54mm_Horizontal
J2, J7: Conn_01x05_Male; PinHeader_1x05_P2.54mm_Horizontal
J3, J5: Conn_02x09_Odd_Even; PinHeader_2x09_P2.54mm_Horizontal
J4: Conn_01x04_Male; PinHeader_1x04_P2.54mm_Horizontal
J6: Conn_PIC_ICSP_ICD; PinHeader_1x06_P2.54mm_Horizontal
R2, R4, R5, R6, R7, R8, R9, R10, R11, R12, R13, R14, R15, R16, R17, R18, R19: 10k; R_Axial_DIN0204_L3.6mm_D1.6mm_P7.62mm_Horizontal
R3: 1k; R_Axial_DIN0204_L3.6mm_D1.6mm_P7.62mm_Horizontal
R20, R21, R22, R23: 220; R_Axial_DIN0204_L3.6mm_D1.6mm_P7.62mm_Horizontal
U1: 74HC00; DIP-14_W7.62mm
U2: BP5293-33; TO-220-3_Vertical
U3: BP5293-50; TO-220-3_Vertical
U4: PIC32MX110F016B-I_SP; DIP-28_W7.62mm
U5: 4051; DIP-16_W7.62mm
U6: TLP785; DIP-4_W7.62mm

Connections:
+5V: C1.2, U1.14, U3.3
GND: C1.1, C2.2, C3.2, C6.1, C7.2, C8.1, C9.2, C10.1, C11.1, C12.1, C14.1, C15.1, C16.1, C17.1, C18.1, C19.1, C20.1, C21.2, C22.1, J1.2, J2.5, J3.1, J3.2, J4.4, J6.3, J7.3, U1.7, U1.9, U1.10, U1.12, U1.13, U2.2, U3.2, U4.8, U4.19, U4.27, U5.6, U5.7, U5.8, U6.3
unnamed: C2.1, C3.1, F1.1, U2.1, U3.1
unnamed: C6.2, R2.2, R3.1
unnamed: C12.2, R12.2, U5.13
unnamed: C14.2, R13.2, U5.14
unnamed: C15.2, R14.2, U5.15
unnamed: C16.2, R15.2, U5.12
unnamed: C17.2, R16.2, U5.1
unnamed: C18.2, R17.2, U5.5
unnamed: C19.2, R18.2, U5.2
unnamed: C20.2, R19.2, U5.4
unnamed: C22.2, U4.20
unnamed: D2.1, R21.1, U6.1
unnamed: D2.2, J7.4, U6.2
unnamed: D3.1, F1.2
unnamed: D3.2, J1.1
unnamed: J2.2, U4.9, U5.11
unnamed: J2.3, U4.10, U5.10
unnamed: J2.4, U4.11, U5.9
unnamed: J3.3, J3.4, R4.2, R12.1
unnamed: J3.5, J3.6, R5.2, R13.1
unnamed: J3.7, J3.8, R6.2, R14.1
unnamed: J3.9, J3.10, R7.2, R15.1
unnamed: J3.11, J3.12, R8.2, R16.1
unnamed: J3.13, J3.14, R9.2, R17.1
unnamed: J3.15, J3.16, R10.2, R18.1
unnamed: J3.17, J3.18, R11.2, R19.1
unnamed: J4.2, U4.18
unnamed: J4.3, U4.17
unnamed: J5.1, U4.24
unnamed: J5.3, U4.25
unnamed: J5.5, U4.26
unnamed: J5.7, U4.7
unnamed: J5.9, U4.6
unnamed: J5.11, U4.5
unnamed: J5.13, U4.4
unnamed: J5.15, U4.3
unnamed: J5.17, U4.2
unnamed: J6.1, R3.2, U4.1
unnamed: J6.4, U4.21
unnamed: J6.5, U4.22
unnamed: J7.1, R22.2
unnamed: J7.2, R23.2
unnamed: J7.5, R21.2
unnamed: R20.2, U4.15, U6.4
unnamed: R22.1, U1.6
unnamed: U1.1, U1.2, U4.16
unnamed: U1.3, U1.4, U1.5
unnamed: U4.23, U5.3
VDD: C7.1, C8.2, C9.1, C10.2, C11.2, C21.1, J2.1, J4.1, J5.2, J5.4, J5.6, J5.8, J5.10, J5.12, J5.14, J5.16, J5.18, J6.2, R2.1, R4.1, R5.1, R6.1, R7.1, R8.1, R9.1, R10.1, R11.1, R20.1, R23.1, U2.3, U4.13, U4.28, U5.16

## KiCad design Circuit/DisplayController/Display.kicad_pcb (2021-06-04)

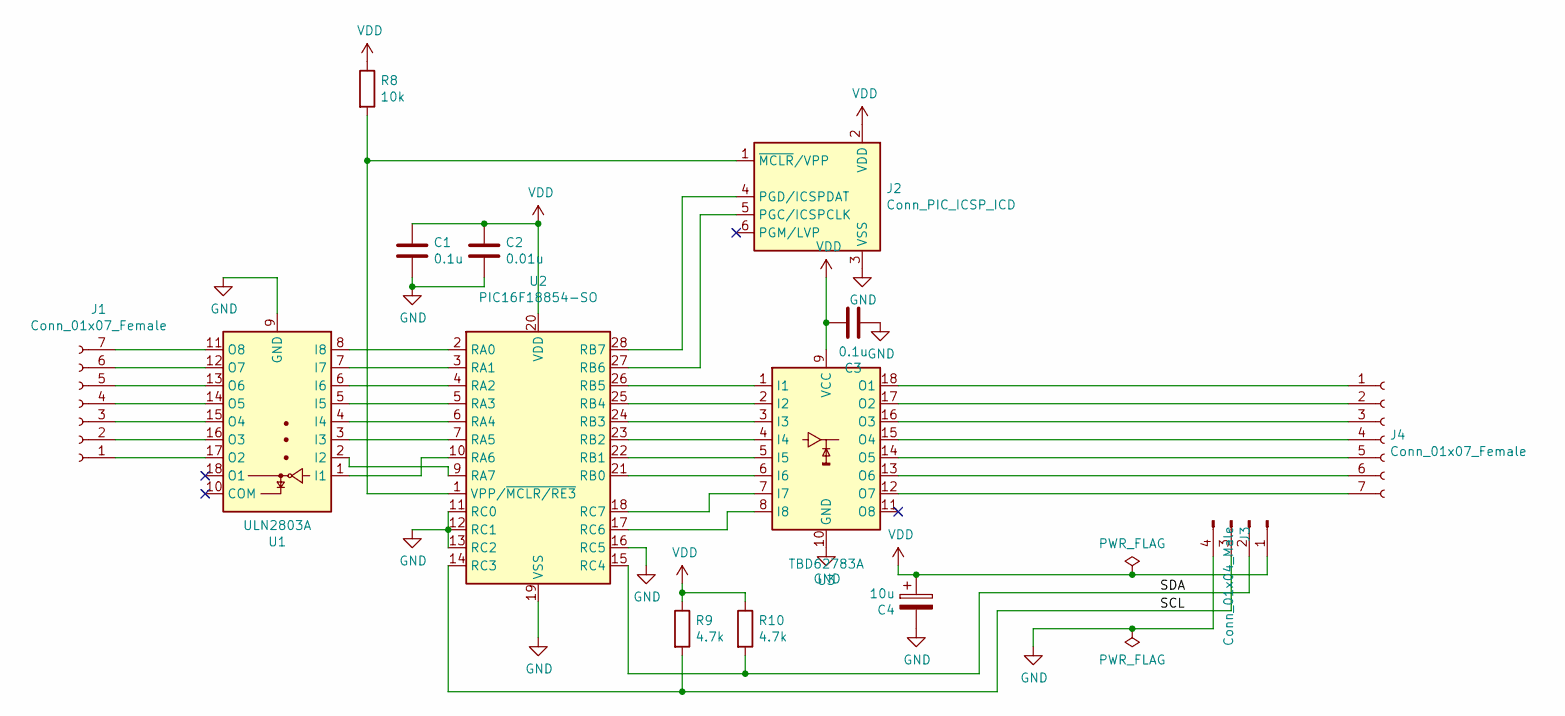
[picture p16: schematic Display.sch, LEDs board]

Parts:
C1, C3: 0.1u; C_Disc_D3.0mm_W1.6mm_P2.50mm
C2: 0.01u; C_Disc_D3.0mm_W2.0mm_P2.50mm
C4: 10u; CP_Radial_D5.0mm_P2.50mm
J1, J4: Conn_01x07_Female; PinSocket_1x07_P2.54mm_Vertical
J2: Conn_PIC_ICSP_ICD; PinHeader_1x06_P2.54mm_Horizontal
J3: Conn_01x04_Male; PinHeader_1x04_P2.54mm_Horizontal
R8: 10k; R_Axial_DIN0204_L3.6mm_D1.6mm_P7.62mm_Horizontal
R9, R10: 4.7k; R_Axial_DIN0204_L3.6mm_D1.6mm_P7.62mm_Horizontal
U1: ULN2803A; DIP-18_W7.62mm
U2: PIC16F18854-SO; DIP-28_W7.62mm
U3: TBD62783A; DIP-18_W7.62mm

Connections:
/SCL: J3.3, R9.2, U2.14 (RC3)
/SDA: J3.2, R10.2, U2.15 (RC4)
GND: C1.1, C2.1, C3.2, C4.2, J2.3 (VSS), J3.4, U1.9 (GND), U2.8 (VSS), U2.11 (RC0), U2.12 (RC1), U2.13 (RC2), U2.16 (RC5), U2.19 (VSS), U3.10 (GND)
unnamed: J1.1, U1.17 (O2)
unnamed: J1.2, U1.16 (O3)
unnamed: J1.3, U1.15 (O4)
unnamed: J1.4, U1.14 (O5)
unnamed: J1.5, U1.13 (O6)
unnamed: J1.6, U1.12 (O7)
unnamed: J1.7, U1.11 (O8)
unnamed: J2.1 (~MCLR~/VPP), R8.2, U2.1 (VPP/~MCLR/RE3)
unnamed: J2.4 (PGD/ICSPDAT), U2.28 (RB7)
unnamed: J2.5 (PGC/ICSPCLK), U2.27 (RB6)
unnamed: J4.1, U3.18 (O1)
unnamed: J4.2, U3.17 (O2)
unnamed: J4.3, U3.16 (O3)
unnamed: J4.4, U3.15 (O4)
unnamed: J4.5, U3.14 (O5)
unnamed: J4.6, U3.13 (O6)
unnamed: J4.7, U3.12 (O7)
unnamed: U1.1 (I1), U2.10 (RA6)
unnamed: U1.2 (I2), U2.9 (RA7)
unnamed: U1.3 (I3), U2.7 (RA5)
unnamed: U1.4 (I4), U2.6 (RA4)
unnamed: U1.5 (I5), U2.5 (RA3)
unnamed: U1.6 (I6), U2.4 (RA2)
unnamed: U1.7 (I7), U2.3 (RA1)
unnamed: U1.8 (I8), U2.2 (RA0)
unnamed: U2.17 (RC6), U3.8 (I8)
unnamed: U2.18 (RC7), U3.7 (I7)
unnamed: U2.21 (RB0), U3.6 (I6)
unnamed: U2.22 (RB1), U3.5 (I5)
unnamed: U2.23 (RB2), U3.4 (I4)
unnamed: U2.24 (RB3), U3.3 (I3)
unnamed: U2.25 (RB4), U3.2 (I2)
unnamed: U2.26 (RB5), U3.1 (I1)
VDD: C1.2, C2.2, C3.1, C4.1, J2.2 (VDD), J3.1, R8.1, R9.1, R10.1, U2.20 (VDD), U3.9 (VCC)

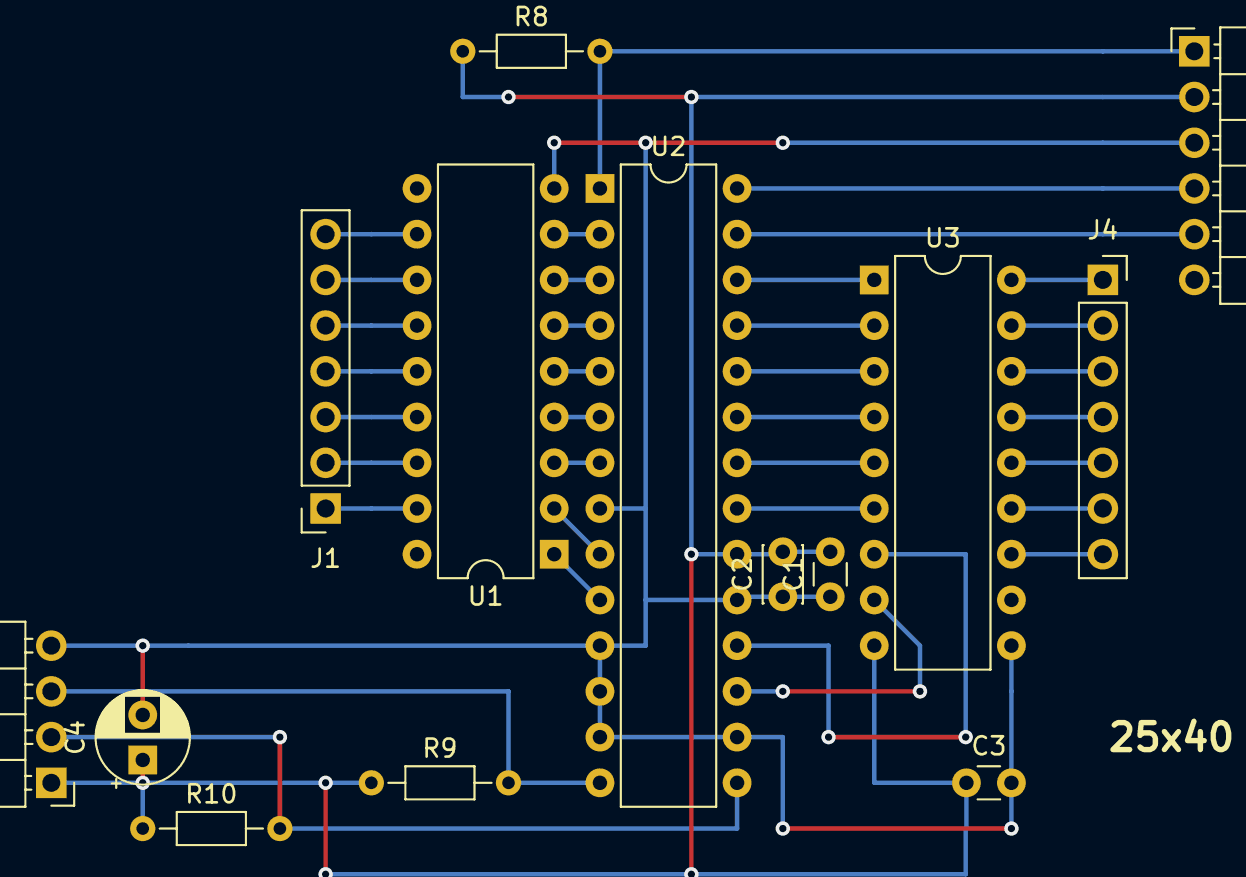
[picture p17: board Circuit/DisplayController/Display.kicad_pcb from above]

Board: 4 copper layers, 14 parts (0 on the bottom side), 37 nets.

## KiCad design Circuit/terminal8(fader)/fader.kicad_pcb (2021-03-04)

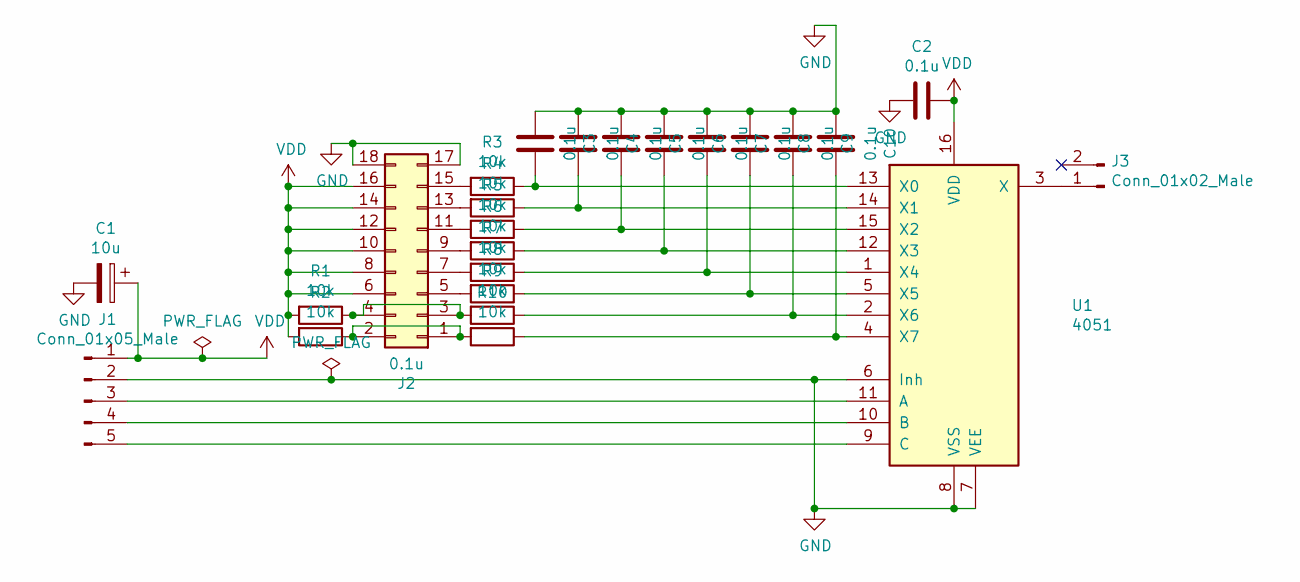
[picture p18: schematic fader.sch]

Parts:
C1: 10u; CP_Radial_D5.0mm_P2.50mm
C2, C3, C4, C5, C6, C7, C8, C9, C10: 0.1u; C_Disc_D3.0mm_W1.6mm_P2.50mm
J1: Conn_01x05_Male; PinHeader_1x05_P2.54mm_Horizontal
J2: 0.1u; PinHeader_2x09_P2.54mm_Horizontal
J3: Conn_01x02_Male; PinHeader_1x02_P2.54mm_Horizontal
R1, R2, R3, R4, R5, R6, R7, R8, R9, R10: 10k; R_Axial_DIN0204_L3.6mm_D1.6mm_P7.62mm_Horizontal
U1: 4051; DIP-16_W7.62mm

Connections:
GND: C1.2, C2.2, C3.2, C4.2, C5.2, C6.2, C7.2, C8.2, C9.2, C10.2, J1.2, J2.17, J2.18, U1.6 (Inh), U1.7 (VEE), U1.8 (VSS)
unnamed: C3.1, R3.1, U1.13 (X0)
unnamed: C4.1, R4.1, U1.14 (X1)
unnamed: C5.1, R5.1, U1.15 (X2)
unnamed: C6.1, R6.1, U1.12 (X3)
unnamed: C7.1, R7.1, U1.1 (X4)
unnamed: C8.1, R8.1, U1.5 (X5)
unnamed: C9.1, R9.1, U1.2 (X6)
unnamed: C10.1, R10.1, U1.4 (X7)
unnamed: J1.3, U1.11 (A)
unnamed: J1.4, U1.10 (B)
unnamed: J1.5, U1.9 (C)
unnamed: J2.1, J2.2, R2.1, R10.2
unnamed: J2.3, J2.4, R1.1, R9.2
unnamed: J2.5, R8.2
unnamed: J2.7, R7.2
unnamed: J2.9, R6.2
unnamed: J2.11, R5.2
unnamed: J2.13, R4.2
unnamed: J2.15, R3.2
unnamed: J3.1, U1.3 (X)
VDD: C1.1, C2.1, J1.1, J2.6, J2.8, J2.10, J2.12, J2.14, J2.16, R1.2, R2.2, U1.16 (VDD)


Board: 2 copper layers, 45.7 x 71.1 mm, 24 parts (0 on the bottom side), 22 nets.

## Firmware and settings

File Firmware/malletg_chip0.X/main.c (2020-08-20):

/**
  Generated Main Source File

  Company:
    Microchip Technology Inc.

  File Name:
    main.c

  Summary:
    This is the main file generated using PIC10 / PIC12 / PIC16 / PIC18 MCUs

  Description:
    This header file provides implementations for driver APIs for all modules selected in the GUI.
    Generation Information :
        Product Revision  :  PIC10 / PIC12 / PIC16 / PIC18 MCUs - 1.81.4
        Device            :  PIC16F18857
        Driver Version    :  2.00
*/

/*
    (c) 2018 Microchip Technology Inc. and its subsidiaries. 
    
    Subject to your compliance with these terms, you may use Microchip software and any 
    derivatives exclusively with Microchip products. It is your responsibility to comply with third party 
    license terms applicable to your use of third party software (including open source software) that 
    may accompany Microchip software.
    
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
    IN NO EVENT WILL MICROCHIP BE LIABLE FOR ANY INDIRECT, SPECIAL, PUNITIVE, 
    INCIDENTAL OR CONSEQUENTIAL LOSS, DAMAGE, COST OR EXPENSE OF ANY KIND 
    WHATSOEVER RELATED TO THE SOFTWARE, HOWEVER CAUSED, EVEN IF MICROCHIP 
    HAS BEEN ADVISED OF THE POSSIBILITY OR THE DAMAGES ARE FORESEEABLE. TO 
    THE FULLEST EXTENT ALLOWED BY LAW, MICROCHIP'S TOTAL LIABILITY ON ALL 
    CLAIMS IN ANY WAY RELATED TO THIS SOFTWARE WILL NOT EXCEED THE AMOUNT 
    OF FEES, IF ANY, THAT YOU HAVE PAID DIRECTLY TO MICROCHIP FOR THIS 
    SOFTWARE.
*/

#include "mcc_generated_files/mcc.h"

#define CHIP_NUMBER 0
#define CHIP_ADDRESS 0x00
#define USER_RX_BUFFER_SIZE 4
#define EUSART_RX_BUFFER_SIZE 8

///from eusart.c

extern void (*EUSART_FramingErrorHandler)(void);
extern void (*EUSART_OverrunErrorHandler)(void);
extern void (*EUSART_ErrorHandler)(void);

extern volatile uint8_t eusartRxHead;
extern volatile uint8_t eusartRxTail;
extern volatile uint8_t eusartRxBuffer[EUSART_RX_BUFFER_SIZE];
extern volatile eusart_status_t eusartRxStatusBuffer[EUSART_RX_BUFFER_SIZE];
extern volatile uint8_t eusartRxCount;
extern volatile eusart_status_t eusartRxLastError;

///for user usart function
uint8_t user_rx_buffer[USER_RX_BUFFER_SIZE] = {0};
uint8_t user_rx_count = 0;

/*
                         Main application
 */
extern void UserRxInterruptHandler(void);

bool change_request=0;

void LED_increment(uint8_t buffer[3]);

void main(void)
{
    uint8_t command_buffer = 0;
    uint8_t LED_buffer[3] = {0};
    uint8_t LED_zeros[3] = {0};
    uint8_t LEDpointer = 0;
    uint8_t timecounter = 0;
    uint8_t statecounter = 0;

    // initialize the device
    SYSTEM_Initialize();
    EUSART_SetRxInterruptHandler(UserRxInterruptHandler);

    // When using interrupts, you need to set the Global and Peripheral Interrupt Enable bits
    // Use the following macros to:

    // Enable the Global Interrupts
    INTERRUPT_GlobalInterruptEnable();

    // Enable the Peripheral Interrupts
    INTERRUPT_PeripheralInterruptEnable();

    // Disable the Global Interrupts
    //INTERRUPT_GlobalInterruptDisable();

    // Disable the Peripheral Interrupts
    //INTERRUPT_PeripheralInterruptDisable();

    TMR2_Start();

    while (1)
    {
        while (!TMR2_HasOverflowOccured())
        {
          if (change_request != 0)
          {
            INTERRUPT_GlobalInterruptDisable();
            command_buffer = user_rx_buffer[0]>>5;
            LED_buffer[0] = 0x7F & (user_rx_buffer[0]<<2 | user_rx_buffer[1]>>6);
            LED_buffer[1] = 0x7F & (user_rx_buffer[1]<<1 | user_rx_buffer[2]>>7);
            LED_buffer[2] = 0x7F & (user_rx_buffer[2]);
            change_request = 0;
            INTERRUPT_GlobalInterruptEnable();
            
            timecounter = 0;
            statecounter = 0;
          }
        }
        switch (command_buffer)
        {
        case 0:
          LED_increment(LED_buffer);
          break;
        
        case 1:
          if (timecounter++ >= 36)
          {
            timecounter = 0;
            if (statecounter==0)
            {
              statecounter = 1;
            }else{
              statecounter = 0;
            }
          }
          
          if (statecounter==0)
          {
            LED_increment(LED_zeros);
          }else{
            LED_increment(LED_buffer);
          }
          
          break;

        case 2:
          if (statecounter >= 5)
          {
            LED_increment(LED_buffer);
          }else
          {
            if (timecounter++ >= 6){
              timecounter = 0;
              statecounter++;
            }
            
            if ((statecounter&1)==0)
            {
              LED_increment(LED_zeros);
            }else{
              LED_increment(LED_buffer);
            }

          }
          break;
        }
    }
}

void LED_increment(uint8_t buffer[3]){
  uint8_t i=0;
  if (IO_LED1_GetValue() == 0){
    IO_LED1_SetHigh();
    IO_LED2_SetLow();
    i=1;
  }else if (IO_LED2_GetValue() == 0){
    IO_LED2_SetHigh();
    IO_LED3_SetLow();
    i=2;
  }else{
    IO_LED3_SetHigh();
    IO_LED1_SetLow();
    i=0;
  }
  IO_LEDA_LAT = buffer[i] & 1;
  IO_LEDB_LAT = (buffer[i]>>1) & 1;
  IO_LEDC_LAT = (buffer[i]>>2) & 1;
  IO_LEDD_LAT = (buffer[i]>>3) & 1;
  IO_LEDE_LAT = (buffer[i]>>4) & 1;
  IO_LEDF_LAT = (buffer[i]>>5) & 1;
  IO_LEDG_LAT = (buffer[i]>>6) & 1;
}

void UserRxInterruptHandler(void){
  
  /******************MCC Code******************/
  eusartRxStatusBuffer[eusartRxHead].status = 0;

  if(RC1STAbits.FERR){
      eusartRxStatusBuffer[eusartRxHead].ferr = 1;
      EUSART_FramingErrorHandler();
  }

  if(RC1STAbits.OERR){
      eusartRxStatusBuffer[eusartRxHead].oerr = 1;
      EUSART_OverrunErrorHandler();
  }
   
  if(eusartRxStatusBuffer[eusartRxHead].status){
      EUSART_ErrorHandler();
  } else {
      /*MCC*/
      /*eusartRxBuffer[*/eusartRxHead++/*] = RC1REG*/;
      if(sizeof(eusartRxBuffer) <= eusartRxHead)
      {
          eusartRxHead = 0;
      }
      eusartRxCount++;
      /*MCC end*/
      
      if (RC1STAbits.RX9D == 1)
      {
        if(RC1REG==CHIP_ADDRESS){
          RC1STAbits.ADDEN = 0;
          change_request = 0;
          user_rx_count = 0;
        }else if(RC1STAbits.ADDEN == 0){
          RC1STAbits.ADDEN = 1;
          change_request = 1;
        }
      }else
      {
        user_rx_buffer[user_rx_count++] = RC1REG;
        if(sizeof(user_rx_buffer) <= user_rx_count)
        {
            user_rx_count = 0;
        }
      }
  }
    
  // or set custom function using EUSART_SetRxInterruptHandler()
  /**********************/

  return;
}

/**
 End of File
*/

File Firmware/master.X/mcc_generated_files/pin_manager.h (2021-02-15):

/**
  System Interrupts Generated Driver File

  @Company:
    Microchip Technology Inc.

  @File Name:
    pin_manager.h

  @Summary:
    This is the generated manager file for the MPLAB(c) Code Configurator device.  This manager
    configures the pins direction, initial state, analog setting.
    The peripheral pin select, PPS, configuration is also handled by this manager.

  @Description:
    This source file provides implementations for MPLAB(c) Code Configurator interrupts.
    Generation Information :
        Product Revision  :  MPLAB(c) Code Configurator - 4.85.0
        Device            :  PIC32MX110F016B
        Version           :  1.02
    The generated drivers are tested against the following:
        Compiler          :  XC32 1.42
        MPLAB             :  MPLAB X 3.55

    Copyright (c) 2013 - 2015 released Microchip Technology Inc.  All rights reserved.

    Microchip licenses to you the right to use, modify, copy and distribute
    Software only when embedded on a Microchip microcontroller or digital signal
    controller that is integrated into your product or third party product
    (pursuant to the sublicense terms in the accompanying license agreement).

    You should refer to the license agreement accompanying this Software for
    additional information regarding your rights and obligations.

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
*/

#ifndef _PIN_MANAGER_H
#define _PIN_MANAGER_H
/**
    Section: Includes
*/
#include <xc.h>
/**
    Section: Device Pin Macros
*/
/**
  @Summary
    Sets the GPIO pin, RA0, high using LATAbits.LATA0.

  @Description
    Sets the GPIO pin, RA0, high using LATAbits.LATA0.

  @Preconditions
    The RA0 must be set to an output.

  @Returns
    None.

  @Param
    None.

  @Example
    <code>
    // Set RA0 high (1)
    channel_AN0_SetHigh();
    </code>

*/
#define channel_AN0_SetHigh()          LATAbits.LATA0 = 1
/**
  @Summary
    Sets the GPIO pin, RA0, low using LATAbits.LATA0.

  @Description
    Sets the GPIO pin, RA0, low using LATAbits.LATA0.

  @Preconditions
    The RA0 must be set to an output.

  @Returns
    None.

  @Param
    None.

  @Example
    <code>
    // Set RA0 low (0)
    channel_AN0_SetLow();
    </code>

*/
#define channel_AN0_SetLow()           LATAbits.LATA0 = 0
/**
  @Summary
    Toggles the GPIO pin, RA0, using LATAbits.LATA0.

  @Description
    Toggles the GPIO pin, RA0, using LATAbits.LATA0.

  @Preconditions
    The RA0 must be set to an output.

  @Returns
    None.

  @Param
    None.

  @Example
    <code>
    // Toggle RA0
    channel_AN0_Toggle();
    </code>

*/
#define channel_AN0_Toggle()           LATAbits.LATA0 ^= 1
/**
  @Summary
    Reads the value of the GPIO pin, RA0.

  @Description
    Reads the value of the GPIO pin, RA0.

  @Preconditions
    None.

  @Returns
    None.

  @Param
    None.

  @Example
    <code>
    uint16_t portValue;

    // Read RA0
    postValue = channel_AN0_GetValue();
    </code>

*/
#define channel_AN0_GetValue()         PORTAbits.RA0
/**
  @Summary
    Configures the GPIO pin, RA0, as an input.

  @Description
    Configures the GPIO pin, RA0, as an input.

  @Preconditions
    None.

  @Returns
    None.

  @Param
    None.

  @Example
    <code>
    // Sets the RA0 as an input
    channel_AN0_SetDigitalInput();
    </code>

*/
#define channel_AN0_SetDigitalInput()  TRISAbits.TRISA0 = 1
/**
  @Summary
    Configures the GPIO pin, RA0, as an output.

  @Description
    Configures the GPIO pin, RA0, as an output.

  @Preconditions
    None.

  @Returns
    None.

  @Param
    None.

  @Example
    <code>
    // Sets the RA0 as an output
    channel_AN0_SetDigitalOutput();
    </code>

*/
#define channel_AN0_SetDigitalOutput() TRISAbits.TRISA0 = 0
/**
  @Summary
    Sets the GPIO pin, RA1, high using LATAbits.LATA1.

  @Description
    Sets the GPIO pin, RA1, high using LATAbits.LATA1.

  @Preconditions
    The RA1 must be set to an output.

  @Returns
    None.

  @Param
    None.

  @Example
    <code>
    // Set RA1 high (1)
    channel_AN1_SetHigh();
    </code>

*/
#define channel_AN1_SetHigh()          LATAbits.LATA1 = 1
/**
  @Summary
    Sets the GPIO pin, RA1, low using LATAbits.LATA1.

  @Description
    Sets the GPIO pin, RA1, low using LATAbits.LATA1.

  @Preconditions
    The RA1 must be set to an output.

  @Returns
    None.

  @Param
    None.

  @Example
    <code>
    // Set RA1 low (0)
    channel_AN1_SetLow();
    </code>

*/
#define channel_AN1_SetLow()           LATAbits.LATA1 = 0
/**
  @Summary
    Toggles the GPIO pin, RA1, using LATAbits.LATA1.

  @Description
    Toggles the GPIO pin, RA1, using LATAbits.LATA1.

  @Preconditions
    The RA1 must be set to an output.

  @Returns
    None.

  @Param
    None.

  @Example
    <code>
    // Toggle RA1
    channel_AN1_Toggle();
    </code>

*/
#define channel_AN1_Toggle()           LATAbits.LATA1 ^= 1
/**
  @Summary
    Reads the value of the GPIO pin, RA1.

  @Description
    Reads the value of the GPIO pin, RA1.

  @Preconditions
    None.

  @Returns
    None.

  @Param
    None.

  @Example
    <code>
    uint16_t portValue;

    // Read RA1
    postValue = channel_AN1_GetValue();
    </code>

*/
#define channel_AN1_GetValue()         PORTAbits.RA1
/**
  @Summary
    Configures the GPIO pin, RA1, as an input.

  @Description
    Configures the GPIO pin, RA1, as an input.

  @Preconditions
    None.

  @Returns
    None.

  @Param
    None.

  @Example
    <code>
    // Sets the RA1 as an input
    channel_AN1_SetDigitalInput();
    </code>

*/
#define channel_AN1_SetDigitalInput()  TRISAbits.TRISA1 = 1
/**
  @Summary
    Configures the GPIO pin, RA1, as an output.

  @Description
    Configures the GPIO pin, RA1, as an output.

  @Preconditions
    None.

  @Returns
    None.

  @Param
    None.

  @Example
    <code>
    // Sets the RA1 as an output
    channel_AN1_SetDigitalOutput();
    </code>

*/
#define channel_AN1_SetDigitalOutput() TRISAbits.TRISA1 = 0
/**
  @Summary
    Sets the GPIO pin, RA2, high using LATAbits.LATA2.

  @Description
    Sets the GPIO pin, RA2, high using LATAbits.LATA2.

  @Preconditions
    The RA2 must be set to an output.

  @Returns
    None.

  @Param
    None.

  @Example
    <code>
    // Set RA2 high (1)
    IO_RA2_SetHigh();
    </code>

*/
#define IO_RA2_SetHigh()          LATAbits.LATA2 = 1
/**
  @Summary
    Sets the GPIO pin, RA2, low using LATAbits.LATA2.

  @Description
    Sets the GPIO pin, RA2, low using LATAbits.LATA2.

  @Preconditions
    The RA2 must be set to an output.

  @Returns
    None.

  @Param
    None.

  @Example
    <code>
    // Set RA2 low (0)
    IO_RA2_SetLow();
    </code>
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

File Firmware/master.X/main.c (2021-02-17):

/**
  Generated Main Source File

  Company:
    Microchip Technology Inc.

  File Name:
    main.c

  Summary:
    This is the main file generated using PIC32MX MCUs

  Description:
    This header file provides implementations for driver APIs for all modules selected in the GUI.
    Generation Information :
        Product Revision  :  PIC32MX MCUs - pic32mx : v1.35
        Device            :  PIC32MX110F016B
        Driver Version    :  2.00
    The generated drivers are tested against the following:
        Compiler          :  XC32 1.42
        MPLAB             :  MPLAB X 3.55
*/

/*
    (c) 2016 Microchip Technology Inc. and its subsidiaries. You may use this
    software and any derivatives exclusively with Microchip products.

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
    IN NO EVENT WILL MICROCHIP BE LIABLE FOR ANY INDIRECT, SPECIAL, PUNITIVE,
    INCIDENTAL OR CONSEQUENTIAL LOSS, DAMAGE, COST OR EXPENSE OF ANY KIND
    WHATSOEVER RELATED TO THE SOFTWARE, HOWEVER CAUSED, EVEN IF MICROCHIP HAS
    BEEN ADVISED OF THE POSSIBILITY OR THE DAMAGES ARE FORESEEABLE. TO THE
    FULLEST EXTENT ALLOWED BY LAW, MICROCHIP'S TOTAL LIABILITY ON ALL CLAIMS IN
    ANY WAY RELATED TO THIS SOFTWARE WILL NOT EXCEED THE AMOUNT OF FEES, IF ANY,
    THAT YOU HAVE PAID DIRECTLY TO MICROCHIP FOR THIS SOFTWARE.

    MICROCHIP PROVIDES THIS SOFTWARE CONDITIONALLY UPON YOUR ACCEPTANCE OF THESE
    TERMS.
*/

#include "mcc_generated_files/mcc.h"
#include "keymap.h"
#include "memorymap.h"
#define _XTAL_FREQ 30000000

void GetKeyValue(_keyvalue*);
void BufferToVelocity(_keyvalue*);
void CheckVelocity(_keyvalue*);

_memorymap pereferences;

/*
                         Main application
 */
int main(void)
{
    _keyvalue keyvalue = {0};

    // initialize the device
    SYSTEM_Initialize();
    load_memorymap(&pereferences);

    while (1)
    {
        do
        {
          GetKeyValue(keyvalue);
        } while (!TMR2_GetElapsedThenClear());

        BufferToVelocity(keyvalue);

        

        CheckVelocity(keyvalue);
    }

    return -1;
}


void CheckVelocity(_keyvalue* keyvalue){
  for (unsigned char i = 0; i < 10; i++)
  {
    for (unsigned char j = 0; j < 8; j++)
    {
      if
    }
  }
}

void BufferToVelocity(_keyvalue* keyvalue){
  unsigned short p = (keyvalue[6][7]->buffer - keyvalue[7][7]->buffer);
  for (char i = 0; i < 10; i++){
    for (char j = 0; j < 8; j++){
      if (keymap[i][j].channeltype==bar)
      {
        if (keyvalue[i][j]->buffer < keyvalue[7][7]->buffer)
        {
          keyvalue[i][j]->buffer = keyvalue[7][7]->buffer + keyvalue[7][7]->buffer - keyvalue[i][j]->buffer;
        }        
        if (keyvalue[i][j]->buffer > keyvalue[7][6]->buffer){
          keyvalue[i][j]->velocity = 127;
        }else{
          keyvalue[i][j]->velocity = (unsigned char)(((unsigned int)(keyvalue[i][j]->buffer - keyvalue[7][7]->buffer)<<7)/p);
        }
        if (keyvalue[i][j]->velocity < preferences.minimum_velocity)
        {
          /* code */
        }
        
      }else if (keymap[i][j].channeltype==fad)
      {
        keyvalue[i][j]->velocity = (keyvalue[i][j]->buffer >> 3);
      }else if (keymap[i][j].channeltype==sw)
      {
        if (keyvalue[i][j]->buffer) keyvalue[i][j]->velocity = 127; else keyvalue[i][j]->velocity = 0;
      }
    }    
  }
}


void GetKeyValue(_keyvalue* keyvalue){
  int i;
  unsigned short buf = 0;
  for ( i = 0; i < 8; i++)
  {
    LATAbits.LATA2 = (i&4)>>2;
    LATAbits.LATA3 = (i&2)>>1;
    LATBbits.LATB4 = (i&1);
    __delay_us(10);

    buf = (unsigned short) ADC1_GetSingleConversion(ADC1_CHANNEL_AN0);
    if (keyvalue[0][i]->buffer < buf) keyvalue[0][i]->buffer = buf;

    buf = (unsigned short) ADC1_GetSingleConversion(ADC1_CHANNEL_AN1);
    if (keyvalue[1][i]->buffer < buf) keyvalue[1][i]->buffer = buf;

    buf = (unsigned short) ADC1_GetSingleConversion(ADC1_CHANNEL_AN2);
    if (keyvalue[2][i]->buffer < buf) keyvalue[2][i]->buffer = buf;

    buf = (unsigned short) ADC1_GetSingleConversion(ADC1_CHANNEL_AN3);
    if (keyvalue[3][i]->buffer < buf) keyvalue[3][i]->buffer = buf;

    buf = (unsigned short) ADC1_GetSingleConversion(ADC1_CHANNEL_AN4);
    if (keyvalue[4][i]->buffer < buf) keyvalue[4][i]->buffer = buf;

    buf = (unsigned short) ADC1_GetSingleConversion(ADC1_CHANNEL_AN5);
    if (keyvalue[5][i]->buffer < buf) keyvalue[5][i]->buffer = buf;

    buf = (unsigned short) ADC1_GetSingleConversion(ADC1_CHANNEL_AN9);
    if (keyvalue[6][i]->buffer < buf) keyvalue[6][i]->buffer = buf;

    buf = (unsigned short) ADC1_GetSingleConversion(ADC1_CHANNEL_AN10);
    if (keyvalue[7][i]->buffer < buf) keyvalue[7][i]->buffer = buf;

    buf = (unsigned short) ADC1_GetSingleConversion(ADC1_CHANNEL_AN11);
    if (keyvalue[8][i]->buffer < buf) keyvalue[8][i]->buffer = buf;

    buf = (unsigned short) IO_RB12_GetValue();
    if (keyvalue[9][i]->buffer < buf) keyvalue[9][i]->buffer = buf;
  }  
}
/**
 End of File
*/

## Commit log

2020-08-09 Change region for 28-pin MCUs
2020-08-09 Revert "Change region for 28-pin MCUs"
    This reverts commit 3ff99377e96ba2532b7dffdd28af3aaaafb2cf97.
2020-08-19 #1 changed pin assign
2020-08-19 !bug fix of & and |
    [main.c]
2020-08-20 chipF mcc + chip0 bug fix
    [main.c]
2020-08-21 bug fix: send message condition
    if (scan_max[i]>0 && scan_max_prev[i]!=scan_max[i])
    →if (scan_max_prev[i]!=scan_max[i])
    [main.c]
2020-09-04 bug fix: switch polarity
    [main.c]
2020-09-04 added MCUs pin assign
2020-09-06 updated hardware (controll panel)
    [NE_controll_panel.FCStd, NW_controll_panel.FCStd]
2020-09-06 extended numbers of faders and buttons
2020-09-06 switch polarity detection added
2020-09-07 8bit circuit (chip#0-5) complete
    [1NW.kicad_pcb, 1NW.sch, 2SW.kicad_pcb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]
2021-02-15 2021/02/15作業再開
    [block0.sch, master.kicad_pcb, master.sch]
2021-02-23 端末全完成
    [fader.kicad_pcb, fader.sch]
2021-02-25 Display分割
    [Mother.kicad_pcb, Mother.sch, terminal5.kicad_pcb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]
2021-02-25 mother回路図作成
    [Display.kicad_pcb, Display.sch, Mother.kicad_pcb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]
2021-02-26 基板完成
    [Display.kicad_pcb, Mother.kicad_pcb, Mother.sch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]
2021-03-04 ECM対策
    [fader.kicad_pcb, terminal1-2-3-6.kicad_pcb, terminal1-2-3-6.sch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]
2021-03-04 回路系全完成
    [Mother.kicad_pcb, Mother.sch, peripheral.sch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]
2021-03-10 回路完成
    [BOM.csv, BOM.ods, BOM2.csv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]
2021-06-11 メイン飛んだ
    [Display.csv, Display.kicad_pcb, Display.sch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]
2021-06-11 メインボード実装完了
    [Mother.kicad_pcb]
2021-06-11 ディスプレイ単独テスト完了
    [Mother.kicad_pcb]
2021-08-03 displayにi2c搭載
